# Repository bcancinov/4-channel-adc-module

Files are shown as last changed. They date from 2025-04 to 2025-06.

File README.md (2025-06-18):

# 4 Channel ADC Module

**Version 0.1** – Prototype for revision and discussion

This repository contains the schematic and supporting documentation for the **4 Channel ADC Module** prototype built in KiCad EDA v9.0.0.

## Table of Contents

1. [Overview](#overview)
2. [Features](#features)
3. [Repository Contents](#repository-contents)
4. [Schematic](#schematic)
5. [User Manual](#user-manual)
6. [Usage](#usage)
7. [Bill of Materials](#bill-of-materials)
8. [License](#license)
9. [Author](#author)

## Overview

The 4 Channel ADC Module is a daughterboard for Trenz TE0720 modules (Zynq™ 7020) designed by NOIRLab to provide high-precision analog-to-digital conversion. It features a multi‑rail power system, low‑noise analog front‑end, high‑speed SAR ADCs, clock synchronization, and both USB-C and Ethernet interfaces.

The following two views show the top and bottom of the assembled PCB, annotated with component group numbers. Refer to the list below for component descriptions.

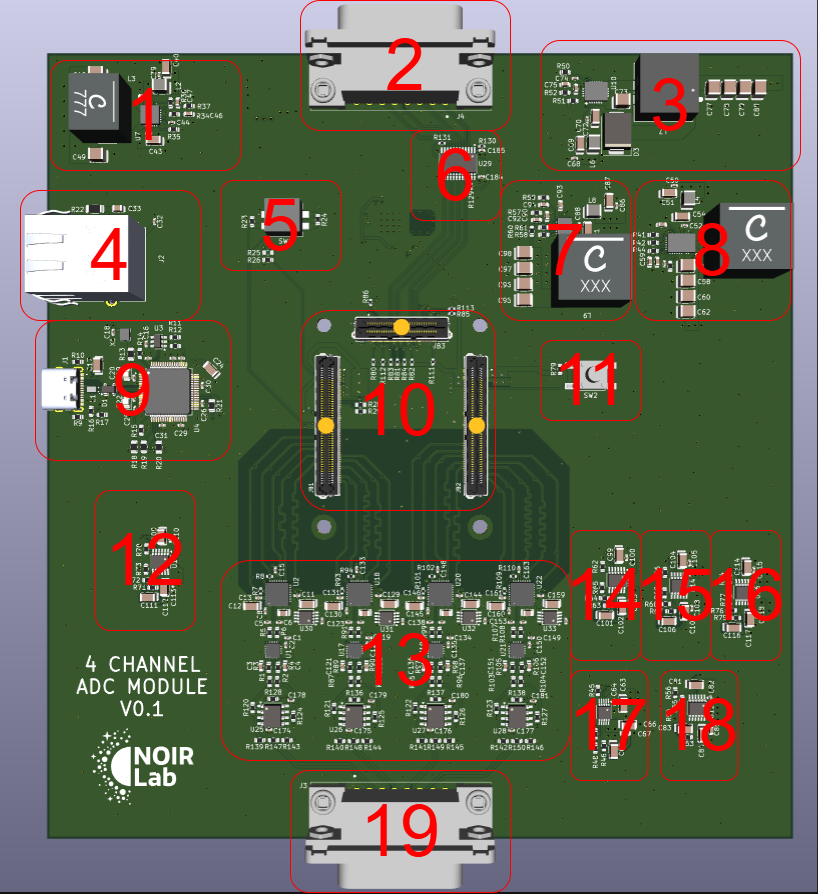
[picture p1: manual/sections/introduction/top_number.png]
Top Side PCB Diagram


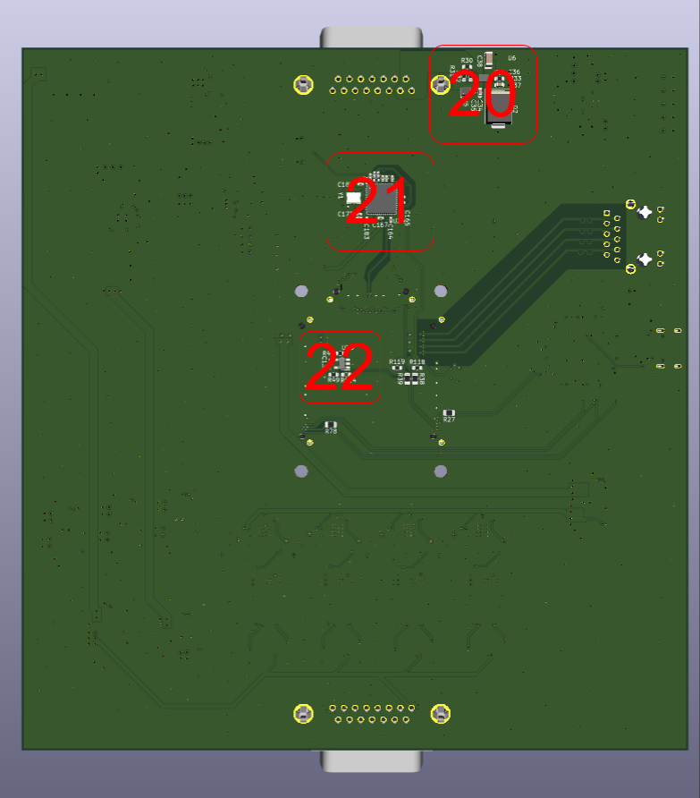
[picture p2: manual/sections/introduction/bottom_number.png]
Bottom Side PCB Diagram


1. Digital 3.3 V DC‑DC Converter.
2. Backplane Connector.
3. Analog –15.5 V DC‑DC Converter.
4. RJ45 Ethernet Connector.
5. Zynq‑SoC Module Mode Switch.
6. Voltage Translator IC.
7. Analog 5.5 V DC‑DC Converter.
8. Analog 15.5 V DC‑DC Converter.
9. FTDI USB‑C Interface.
10. Zynq‑SoC Module.
11. Zynq‑SoC Reset Button.
12. Digital 2.5 V LDO.
13. 4 Channel Video Front‑End and ADC.
14. Analog 5 V LDO.
15. Analog 2.5 V LDO.
16. Analog 4.2 V LDO.
17. Analog 15 V LDO.
18. Analog –15 V LDO.
19. Video Input Connector.
20. 12 V Power Input Protection.
21. Clock Generator.
22. EEPROM.

## Features

* **Dimensions:** 162 mm × 171 mm, six‑layer impedance‑controlled PCB
* **ADC Front‑End:** Fully differential, low‑noise amplifiers (ADA4945‑1 & LTC2387‑18)
* **Main Processor:** Zynq 7020 SoC-Module (TE0720-04-62I33MA)
* **Clock Gen:** Si5342‑D jitter attenuator for 10 MHz sync
* **Interfaces:** USB‑C (FT2232HL), Gigabit Ethernet (RJ45)
* **Power:** 12 V VIN protection, multi‑rail DC‑DC converters & LDOs
* **Backplane:** Sync clock, start, error, power rails

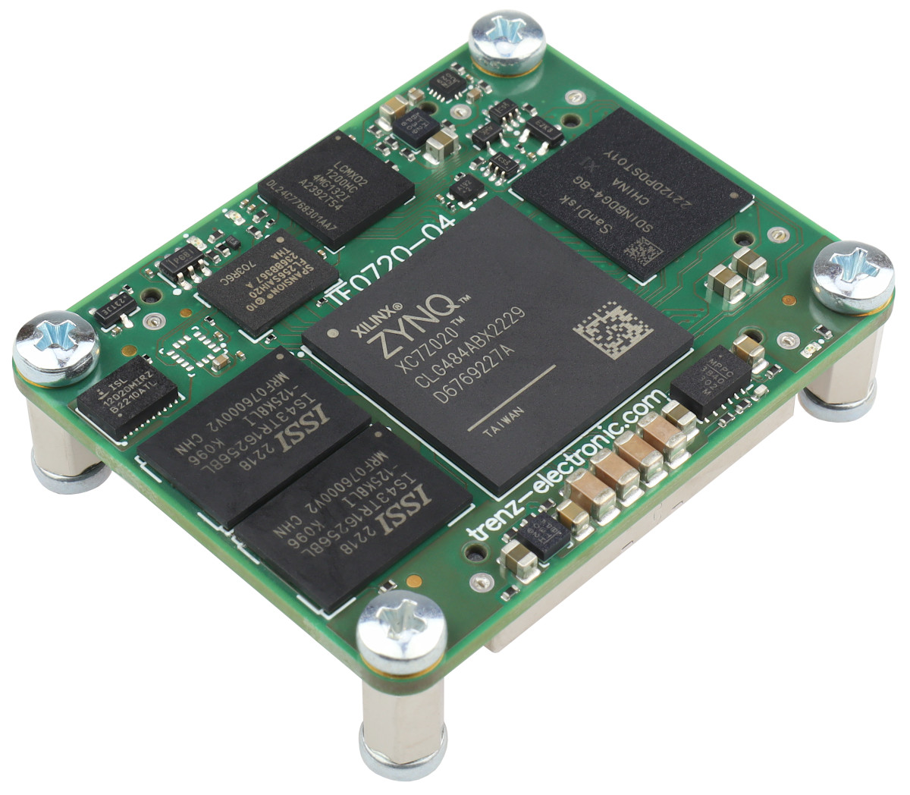
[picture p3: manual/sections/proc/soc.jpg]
Zynq 7020 SoC-Module


* `README.md` – This file
* `BOM.csv` – Bill of Materials
* `adc_board_prot.pdf` – Complete schematic PDF
* `adc_board_prot.kicad_pro` – KiCad project file
* `*.kicad_sch` – Schematic sheets (power, clock\_gen, adc, ftdi, ethernet, connectors, converters, misc, b2b\_jb1-3, power variants)
* `*.kicad_pcb` – PCB layout file
* `*.kicad_prl`, `*.kicad_prl` – PCB drill/paper list
* `*.kicad_sym`, `lib.kicad_sym` – Symbol libraries
* `lib.pretty/` – Footprint library

Other directories:

* `sim/` – LTSpice & LTPowerCAD simulations
* `step/` – STEP model files
* `docs/` – Documentation sources
* `manual/` – User manual PDF

## Schematic

The complete schematic is available as a PDF:

* [Download the schematic (PDF)](./adc_board_prot.pdf)

## User Manual

A detailed manual covering module description, power rails, front‑end design, and connectors can be found here:

* [Read the user manual (PDF)](manual/manual.pdf)

## Usage

1. Install [KiCad EDA 9.0.0](https://www.kicad.org).
2. Open **adc\_board\_prot.kicad\_pro** in KiCad.
3. Review schematic and BOM before fabrication.
4. Use the manual for detailed functional descriptions and assembly notes.

## Bill of Materials

A complete list of components and part numbers is provided in:

* `BOM.csv`

## License

This project is released under the **MIT License**.

## Author

**Braulio Cancino Vera**
NOIRLab
[braulio.cancino@noirlab.edu](mailto:braulio.cancino@noirlab.edu)
Date: June 17, 2025

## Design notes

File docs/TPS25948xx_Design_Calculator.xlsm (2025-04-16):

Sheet: Calculation Sheet
TPS25948xx Design Calculation Tool
 | Constants Cells
 | Input/SelectCells
 | Calculation Cells
 | Calculated, but can be over-ridden by user
 | Error Cells, Must be Fixed
Parameter | Description | Value | Units | Tolerance | Recommended Value
VIN (max) | Maximum Operating input voltage (magnitude) | 12.00 | V
OVLO Set Point | Desired Over Voltage Lockout Set Point | 14.00 | V | 3.0%
UVLO Set Point | Desired Undervoltage Threshold (VIN Rising) | 10.00 | V | 3.0%
VUVP | Internal Undervoltage Protection Threshold (VIN Rising) | 2.53 | V | 3.0%
Cout | Load Capacitance | 50.0 | uF | 10.0%
 | Is there downstream load present other than load cap at startup? | YES
VONTH (CR) (V) | constant resistance load turn on threshold voltage | 0.0 | V
RLOAD (STARTUP) (Ω) | CR load at startup | 4.0 | Ohm
VONTH (CC) (V) | constant current load turn on threshold voltage | 3.0 | V
ILOAD (STARTUP) (A) | CC load at startup | 0.0 | A
VONTH (CP) (V) | constant power load turn on threshold voltage | 8.0 | V
PLOAD (STARTUP) (W) | CP load at startup | 0.0 | W
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

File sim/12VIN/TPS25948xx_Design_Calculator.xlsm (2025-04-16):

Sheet: Calculation Sheet
TPS25948xx Design Calculation Tool
 | Constants Cells
 | Input/SelectCells
 | Calculation Cells
 | Calculated, but can be over-ridden by user
 | Error Cells, Must be Fixed
Parameter | Description | Value | Units | Tolerance | Recommended Value
VIN (max) | Maximum Operating input voltage (magnitude) | 13.00 | V
OVLO Set Point | Desired Over Voltage Lockout Set Point | 14.00 | V | 3.0%
UVLO Set Point | Desired Undervoltage Threshold (VIN Rising) | 10.00 | V | 3.0%
VUVP | Internal Undervoltage Protection Threshold (VIN Rising) | 2.53 | V | 3.0%
Cout | Load Capacitance | 10.0 | uF | 10.0%
 | Is there downstream load present other than load cap at startup? | YES
VONTH (CR) (V) | constant resistance load turn on threshold voltage | 0.0 | V
RLOAD (STARTUP) (Ω) | CR load at startup | 4.0 | Ohm
VONTH (CC) (V) | constant current load turn on threshold voltage | 3.0 | V
ILOAD (STARTUP) (A) | CC load at startup | 0.0 | A
VONTH (CP) (V) | constant power load turn on threshold voltage | 8.0 | V
PLOAD (STARTUP) (W) | CP load at startup | 0.0 | W
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

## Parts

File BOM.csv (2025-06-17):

Reference | Value | Qty | M | MPN | Description
C1,C2,C8,C9,C11,C13,C15,C16,C18,C20,C21,C23,C25,C26,C27,C28,C29,C30,C31,C32,C35,C39,C41,C50,C52,C56,C64,C68,C70,C74,C82,C86,C88,C100,C103,C105,C108,C110,C113,C115,C118,C119,C120,C126,C127,C129,C131,C132,C133,C134,C135,C141,C142,C144,C146,C148,C149,C150,C156,C157,C159,C161,C163,C174,C175,C176,C177,C178,C179,C180,C181,C184,C185 | 0.1uF | 73 | MURATA | GCM155R71H104KE02J | 0.1 µF ±10% 50V Ceramic Capacitor X7R 0402 (1005 Metric)
C3,C4,C121,C122,C136,C137,C151,C152 | 300pF | 8 | MURATA | GCM1885C2A301FA16J | 300 pF ±1% 100V Ceramic Capacitor C0G, NP0 0603 (1608 Metric)
C5,C6,C123,C124,C138,C139,C153,C154 | 180pF | 8 | MURATA | GRT1555C1H181FA02D | 180 pF ±1% 50V Ceramic Capacitor C0G, NP0 0402 (1005 Metric)
C7,C125,C140,C155 | 10uF | 4 | MURATA | GRM21BZ71C106KE15L | 10 µF ±10% 16V Ceramic Capacitor X7R 0805 (2012 Metric)
C10,C12,C17,C24,C38,C40,C43,C51,C54,C69,C72,C87,C91,C128,C130,C143,C145,C158,C160 | 10uF | 19 | TAIYO | GMK316AB7106KL-TR | 10 µF ±10% 35V Ceramic Capacitor X7R 1206 (3216 Metric)
C14,C42,C71,C89,C182,C183 | 0.1uF | 6 | MURATA | GCM155R71C104KA55J | 0.1 µF ±10% 16V Ceramic Capacitor X7R 0402 (1005 Metric)
C19,C22 | 1uF | 2 | MURATA | GCM21BR71H105KA03L | 1 µF ±10% 50V Ceramic Capacitor X7R 0805 (2012 Metric)
C33 | 100pF | 1 | WURTH | 885342207015 | 100 pF ±10% 1000V (1kV) Ceramic Capacitor X7R 0805 (2012 Metric)
C34 | 1uF | 1 | TDK | CGA3E1X7R1V105K080DC | 1 µF ±10% 35V Ceramic Capacitor X7R 0603 (1608 Metric)
C36 | 2.7nF | 1 | MURATA | GRM1885C1H272JA01D | 2700 pF ±5% 50V Ceramic Capacitor C0G, NP0 0603 (1608 Metric)
C37 | 4.3nF | 1 | MURATA | GRM1885C1H432JA01D | 4300 pF ±5% 50V Ceramic Capacitor C0G, NP0 0603 (1608 Metric)
C44 | 10nF | 1 | MURATA | GCM155R71H103KA55D | 10000 pF ±10% 50V Ceramic Capacitor X7R 0402 (1005 Metric)
C45 | 1uF | 1 | TAIYO | UMK107AB7105KA-T | 1 µF ±10% 50V Ceramic Capacitor X7R 0603 (1608 Metric)
C46 | 220p | 1 | MURATA | GCM1885C2A221FA16D | 220 pF ±1% 100V Ceramic Capacitor C0G, NP0 0603 (1608 Metric)
C47 | 47pF | 1 | MURATA | GCM1885C2A470FA16D | 47 pF ±1% 100V Ceramic Capacitor C0G, NP0 0603 (1608 Metric)
C48,C49,C57,C58,C60,C62,C77,C78,C79,C80,C95,C96,C97,C98 | 47u | 14 | TAIYO YUDEN | TMK325ABJ476MM-P | 47 µF ±20% 25V Ceramic Capacitor X5R 1210 (3225 Metric)
C55 | 4.7u | 1 | MURATA | GRT188R61E475KE13D | 4.7 µF ±10% 25V Ceramic Capacitor X5R 0603 (1608 Metric)
C59,C75 | 1nF | 2 | MURATA | GCM1885C2A102JA16D | 1000 pF ±5% 100V Ceramic Capacitor C0G, NP0 0603 (1608 Metric)
C61 | 5.1pF | 1 | KEMET | CBR06C519C5GACAUTO | 5.1 pF ±0.25pF 50V Ceramic Capacitor C0G, NP0 0603 (1608 Metric)
C63,C65,C66,C81,C83,C84,C99,C101,C102,C104,C106,C107,C109,C111,C112,C114,C116,C117 | 4.7uF | 18 | MURATA | GRM31CZ72A475KE11L | 4.7 µF ±10% 100V Ceramic Capacitor X7R 1206 (3216 Metric)
C67,C85 | 0.1uF | 2 | TAIYO | HMK107B7104KAHT | 0.1 µF ±10% 100V Ceramic Capacitor X7R 0603 (1608 Metric)
C73 | 4.7uF | 1 | KYOCERA | 12101C475K4Z2A | 4.7 µF ±10% 100V Ceramic Capacitor X7R 1210 (3225 Metric)
C76 | 27pF | 1 | MURATA | GCM1885C2A270JA16D | 27 pF ±5% 100V Ceramic Capacitor C0G, NP0 0603 (1608 Metric)
C90 | 150pF | 1 | KYOCERA | KGM15ACG1E151FT | 150 pF ±1% 25V Ceramic Capacitor C0G, NP0 0603 (1608 Metric)
C92 | 3nF | 1 | MURATA | GCM1885C1H302GA16D | 3000 pF ±2% 50V Ceramic Capacitor C0G, NP0 0603 (1608 Metric)
C93,C94 | 1uF | 2 | TAIYO | GMK107AB7105KAHT | 1 µF ±10% 35V Ceramic Capacitor X7R 0603 (1608 Metric)
C162,C164,C165,C166,C167,C168,C169,C170,C171,C172,C173 | 1uF | 11 | VENKEL | C0402X7R100-105KNP-CT | 1 µF ±10% 10V Ceramic Capacitor X7R 0402 (1005 Metric)
D1 | PRTR5V0U2X,215 | 1 | NEXPERIA | PRTR5V0U2X,215 | Ultra low capacitance double rail-to-rail ESD protection diode, SOT-143
D2 | B520C-13-F | 1 | DIODES | B520C-13-F | DIODE SCHOTTKY 20V 5A SMC
D3 | B560CX | 1 | DIODES | B560CX-13 | Diode 60 V 5A Surface Mount SMC
J1 | USB4105-GF-A | 1 | GCT | USB4105-GF-A | USB-C (USB TYPE-C) USB 2.0 Receptacle Connector 24 (16+8 Dummy) Position Surface Mount, Right Angle; Through Hole
J2 | TMJG4820GENL | 1 | TAOGLAS | TMJG4820GENL | 1 Port RJ45Through Hole 1G Base-T, AutoMDIX
J3,J4 | 5747841-4 | 2 | TE | 5747841-4 | 15-pin D-SUB connector, pins (male) (low-density/2 columns), Mounting Hole
JB1,JB2 | TE0720-JB1,TE0720-JB2 | 2 | SAMTEC | LSHM-150-04.0-L-DV-A-S-K-TR | 100 Position Connector Self Mating, Non-Gendered, Hermaphroditic Surface Mount Gold
JB3 | TE0720-JB3 | 1 | SAMTEC | LSHM-130-04.0-L-DV-A-S-K-TR | 60 Position Connector Self Mating, Non-Gendered, Hermaphroditic Surface Mount Gold
L1 | 744233670 | 1 | WURTH | 744233670 | 2 Line Common Mode Choke Surface Mount 67 Ohms 320mA DCR 240mOhm
L2,L4,L6,L8 | 250 nH | 4 | WURTH ELEKTRONIK | 74479290125 | 250 nH Unshielded Molded Inductor 9.35 A 31mOhm Max 1210 (3225 Metric)
L3 | 0.8uH | 1 | COILCRAFT | XGL1010-801MED | 800 nH Shielded Molded Inductor 48 A 1.1mOhm Max Nonstandard
L5,L9 | 2.2uH | 2 | COILCRAFT | XGL1313-222MED | 2.2 µH Shielded Molded Inductor 45.1 A 1.6mOhm Max 2-SMD,Inductor
L7 | 3.3u | 1 | EATON | DRQ125-3R3-R | Shielded 2 Coil Inductor Array 12.34 µH Inductance - Connected in Series 3.084 µH Inductance - Connected in Parallel 6.3mOhm DC Resistance (DCR) - Parallel 9.26 A Nonstandard
R1,R2,R3,R4,R87,R88,R89,R90,R95,R96,R97,R98,R103,R104,R105,R106,R120,R121,R122,R123,R124,R125,R126,R127 | 1k | 24 | PANASONIC | ERA-3AEB102V | 1 kOhms ±0.1% 0.1W, 1/10W Chip Resistor 0603 (1608 Metric) Automotive AEC-Q200 Thin Film
R5,R6,R91,R92,R99,R100,R107,R108 | 24.9 | 8 | VISHAY | CRCW060324R9FKEA | 24.9 Ohms ±1% 0.1W, 1/10W Chip Resistor 0603 (1608 Metric) Automotive AEC-Q200 Thick Film
R7,R8,R93,R94,R101,R102,R109,R110,R117 | 100 | 9 | VISHAY | CRCW0402100RFKEDHP | 100 Ohms ±1% 0.2W, 1/5W Chip Resistor 0402 (1005 Metric) Automotive AEC-Q200, Pulse Withstanding Thick Film
R9,R10 | 5.1k | 2 | VISHAY | CRCW06035K10FKEA | 5.1 kOhms ±1% 0.1W, 1/10W Chip Resistor 0603 (1608 Metric) Automotive AEC-Q200 Thick Film
R11 | 2k | 1 | VISHAY | CRCW06032K00FKEA | 2 kOhms ±1% 0.1W, 1/10W Chip Resistor 0603 (1608 Metric) Automotive AEC-Q200 Thick Film
R12,R17,R23,R24,R25,R28,R29,R40,R60,R79,R118,R119,R129,R130,R131,R139,R140,R141,R142,R143,R144,R145,R146 | 10K,10k | 23 | VISHAY | CRCW060310K0FKEA | 10 kOhms ±1% 0.1W, 1/10W Chip Resistor 0603 (1608 Metric) Automotive AEC-Q200 Thick Film
R13,R18,R19,R20,R21,R27,R38,R39,R78 | 22 | 9 | VISHAY | CRCW080522R0FKEAHP | 22 Ohms ±1% 0.5W, 1/2W Chip Resistor 0805 (2012 Metric) Automotive AEC-Q200, Pulse Withstanding Thick Film
R14 | 12k | 1 | VISHAY | CRCW060312K0FKEA | 12 kOhms ±1% 0.1W, 1/10W Chip Resistor 0603 (1608 Metric) Automotive AEC-Q200 Thick Film
R15,R48,R56,R61,R65,R69,R73,R77,R147,R148,R149,R150 | 1k | 12 | VISHAY | CRCW06031K00FKEA | 1 kOhms ±1% 0.1W, 1/10W Chip Resistor 0603 (1608 Metric) Automotive AEC-Q200 Thick Film
R16 | 4k7 | 1 | VISHAY | CRCW06034K70FKEA | 4.7 kOhms ±1% 0.1W, 1/10W Chip Resistor 0603 (1608 Metric) Automotive AEC-Q200 Thick Film
R22 | 1M | 1 | VISHAY | CRCW12061M00JNEAHP | 1 MOhms ±5% 0.75W, 3/4W Chip Resistor 1206 (3216 Metric) Automotive AEC-Q200, Pulse Withstanding Thick Film
R26,R45,R49,R54,R62,R66,R70,R74,R114 | 0 | 9 | VISHAY | CRCW06030000Z0EA | 0 Ohms Jumper Chip Resistor 0603 (1608 Metric) Automotive AEC-Q200 Thick Film
R30 | 470k | 1 | VISHAY | CRCW0603470KFKEA | 470 kOhms ±1% 0.1W, 1/10W Chip Resistor 0603 (1608 Metric) Automotive AEC-Q200 Thick Film
R31,R44 | 18.7k | 2 | VISHAY | CRCW060318K7FKEA | 18.7 kOhms ±1% 0.1W, 1/10W Chip Resistor 0603 (1608 Metric) Automotive AEC-Q200 Thick Film
R32 | 46.4k | 1 | VISHAY | CRCW060346K4FKEA | 46.4 kOhms ±1% 0.1W, 1/10W Chip Resistor 0603 (1608 Metric) Automotive AEC-Q200 Thick Film
R33 | 1050 | 1 | VISHAY | CRCW06031K05FKEA | 1.05 kOhms ±1% 0.1W, 1/10W Chip Resistor 0603 (1608 Metric) Automotive AEC-Q200 Thick Film
R34 | 6.98k | 1 | VISHAY | CRCW06036K98FKTA | 6.98 kOhms ±1% 0.1W, 1/10W Chip Resistor 0603 (1608 Metric) Automotive AEC-Q200 Thick Film
R35 | 17.8k | 1 | VISHAY | CRCW060317K8FKEA | 17.8 kOhms ±1% 0.1W, 1/10W Chip Resistor 0603 (1608 Metric) Automotive AEC-Q200 Thick Film
R36 | 100k | 1 | VISHAY | CRCW0603100KFKEA | 100 kOhms ±1% 0.1W, 1/10W Chip Resistor 0603 (1608 Metric) Automotive AEC-Q200 Thick Film
R37 | 22.1k | 1 | VISHAY | CRCW060322K1FKEA | 22.1 kOhms ±1% 0.1W, 1/10W Chip Resistor 0603 (1608 Metric) Automotive AEC-Q200 Thick Film
R41 | 110k | 1 | VISHAY | CRCW0603110KFKEA | 110 kOhms ±1% 0.1W, 1/10W Chip Resistor 0603 (1608 Metric) Automotive AEC-Q200 Thick Film
R42 | 7.5k | 1 | VISHAY | CRCW06037K50FKEA | 7.5 kOhms ±1% 0.1W, 1/10W Chip Resistor 0603 (1608 Metric) Automotive AEC-Q200 Thick Film
R43,R52 | 20k | 2 | VISHAY | CRCW060320K0FKEA | 20 kOhms ±1% 0.1W, 1/10W Chip Resistor 0603 (1608 Metric) Automotive AEC-Q200 Thick Film
R46,R53 | 150k | 2 | VISHAY | TNPW0603150KBEEA | 150 kOhms ±0.1% 0.21W Chip Resistor 0603 (1608 Metric) Anti-Sulfur, Automotive AEC-Q200, Moisture Resistant Thin Film
R47,R55 | 47.5k | 2 | VISHAY | CRCW060347K5FKEA | 47.5 kOhms ±1% 0.1W, 1/10W Chip Resistor 0603 (1608 Metric) Automotive AEC-Q200 Thick Film
R50 | 43.2k | 1 | VISHAY | CRCW060343K2FKEA | 43.2 kOhms ±1% 0.1W, 1/10W Chip Resistor 0603 (1608 Metric) Automotive AEC-Q200 Thick Film
R51 | 187k | 1 | VISHAY | CRCW0603187KFKEA | 187 kOhms ±1% 0.1W, 1/10W Chip Resistor 0603 (1608 Metric) Automotive AEC-Q200 Thick Film
R57 | 3.09k | 1 | VISHAY | CRCW06033K09FKEA | 3.09 kOhms ±1% 0.1W, 1/10W Chip Resistor 0603 (1608 Metric) Automotive AEC-Q200 Thick Film
R58 | 47k | 1 | VISHAY | CRCW060347K0FKEA | 47 kOhms ±1% 0.1W, 1/10W Chip Resistor 0603 (1608 Metric) Automotive AEC-Q200 Thick Film
R59 | 54.9k | 1 | VISHAY | CRCW060354K9FKEA | 54.9 kOhms ±1% 0.1W, 1/10W Chip Resistor 0603 (1608 Metric) Automotive AEC-Q200 Thick Film
R63 | 49.9k | 1 | VISHAY | TNPW060349K9BEEA | 49.9 kOhms ±0.1% 0.21W Chip Resistor 0603 (1608 Metric) Anti-Sulfur, Automotive AEC-Q200, Moisture Resistant Thin Film
R64 | 14k | 1 | VISHAY | CRCW060314K0FKEA | 14 kOhms ±1% 0.1W, 1/10W Chip Resistor 0603 (1608 Metric) Automotive AEC-Q200 Thick Film
R67,R71 | 24.9k | 2 | VISHAY | TNPW060324K9BEEN | 24.9 kOhms ±0.1% 0.21W Chip Resistor 0603 (1608 Metric) Anti-Sulfur, Automotive AEC-Q200, Moisture Resistant Thin Film
R68,R72 | 6.98k | 2 | VISHAY | CRCW06036K98FKEA | 6.98 kOhms ±1% 0.1W, 1/10W Chip Resistor 0603 (1608 Metric) Automotive AEC-Q200 Thick Film
R75 | 42.2k | 1 | VISHAY | TNPW060342K2BEEA | 42.2 kOhms ±0.1% 0.21W Chip Resistor 0603 (1608 Metric) Anti-Sulfur, Automotive AEC-Q200, Moisture Resistant Thin Film
R76 | 13k | 1 | VISHAY | CRCW060313K0FKEA | 13 kOhms ±1% 0.1W, 1/10W Chip Resistor 0603 (1608 Metric) Automotive AEC-Q200 Thick Film
R80,R81,R82,R83,R84,R85,R86,R111,R112,R113 | 100k | 10 | VISHAY | CRCW0402100KFKED | 100 kOhms ±1% 0.063W, 1/16W Chip Resistor 0402 (1005 Metric) Automotive AEC-Q200 Thick Film
R128,R136,R137,R138 | 665 | 4 | VISHAY | CRCW0603665RFKEA | 665 Ohms ±1% 0.1W, 1/10W Chip Resistor 0603 (1608 Metric) Automotive AEC-Q200 Thick Film
SW1 | SDA02H1SBDR | 1 | C&K | SDA02H1SBDR | Dip Switch SPST 2 Position Surface Mount Slide (Standard) Actuator 25mA 24VDC
SW2 | FSM6JSMATR | 1 | TE | FSM6JSMATR | Tactile Switch SPST-NO Top Actuated Surface Mount
U1,U17,U19,U21 | ADA4945-1 | 4 | ANALOG | ADA4945-1ACPZ-RL | ADC Driver IC Data Acquisition 16-LFCSP (3x3)
U2,U18,U20,U22 | LTC2387-18 | 4 | ANALOG | LTC2387IUH-18#TRPBF | 18 Bit Analog to Digital Converter 1 Input 1 SAR 32-QFN (5x5)
U3 | 93AA56BT-I/OT | 1 | MICROCHIP | 93AA56BT-I/OT | Serial EEPROM, 93 Series, 16-bit word, 1.8V, SOT-23
U4 | FT2232HL | 1 | FTDI | FT2232HL-REEL | USB Bridge, USB to UART,FIFO USB 2.0 UART Interface 64-LQFP (10x10)
U5 | TVS1800DRV | 1 | TEXAS INSTRUMENTS | TVS1800DRVR | Flat-Clamp Surge Protection Device. 18Vrwm, WSON-6
U6 | TPS259480AYWPR | 1 | TEXAS INSTRUMENTS | TPS259480AYWPR | Electronic Fuse Regulator High-Side 8A 12-DSBGA (2.43x1.74)
U7 | LT8642S | 1 | ANALOG | LT8642SEV#PBF | Buck Switching Regulator IC Positive Adjustable 0.597V 1 Output 10A 24-TFQFN Exposed Pad
U8 | LT8350S | 1 | ANALOG | LT8350SAV#PBF | Buck-Boost Switching Regulator IC Positive Adjustable 1V 1 Output 6A 32-TFQFN Exposed Pad, 28 Leads
U9 | LT3042 | 1 | ANALOG DEVICES | LT3042EMSE#TRPBF | 200mA, Adjustable, Ultralow Noise, Ultrahigh PSRR RF Linear Regulator, MSOP-10
U10 | LT3579 | 1 | ANALOG | LT3579EUFD#PBF | Boost, Charge Pump, Cuk, Flyback, SEPIC Switching Regulator IC Positive or Negative Adjustable 1.215V 1 Output 6A (Switch) 20-WFQFN Exposed Pad
U11 | LT3093 | 1 | ANALOG | LT3093EMSE#PBF | -200mA, Adjustable, Ultralow Noise, Ultrahigh PSRR RF Negative Linear Regulator, MSOP-12
U12 | LT8624S | 1 | ANALOG | LT8624SAV#PBF | Buck Switching Regulator IC Positive Adjustable 0V 1 Output 4A 20-TFQFN Exposed Pad
U13,U14,U15,U16 | LT3045 | 4 | ANALOG | LT3045EMSE#TRPBF | 500mA, Adjustable, Ultralow Noise, Ultrahigh PSRR Linear Regulator, MSOP-12
U23 | 24LC16BT-I/OT | 1 | MICROCHIP | 24LC16BT-I/OT | EEPROM Memory IC 16Kbit I2C 400 kHz 900 ns SOT-23-5
U24 | Si5342A-D | 1 | SKYWORKS | SI5342A-D-GM | Jitter Attenuator/Clock Multiplier, 2 channel, Fractional, 0.001-1028 MHz, QFN-44
U25,U26,U27,U28 | ADA4898-2 | 4 | ANALOG | ADA4898-2YRDZ-R7 | Dual High Voltage, Low Noise, Low Distortion, Unity-Gain Stable, High Speed Op Amp, SOIC-8-1EP
U29 | SN74AXC8T245-Q1 | 1 | TEXAS | SN74AXC8T245QPWRQ1 | Translation Transceiver 1 Element 8 Bit per Element Tri-State, Non-Inverted Output 24-TSSOP
U30,U31,U32,U33 | LTC6655BHMS8-4.096#PBF | 4 | ANALOG | LTC6655BHMS8-4.096#PBF | Series Voltage Reference IC Fixed 4.096V V ±0.025% 5 mA 8-MSOP
X1 | ECS-2520MVLC-120-CN-TR | 1 | ECS | ECS-2520MVLC-120-CN-TR
Y1 | CX3225SB48000D0FLJCC | 1 | KYOCERA | CX3225SB48000D0FLJCC | 48 MHz ±10ppm Crystal 8pF 50 Ohms 4-SMD, No Lead

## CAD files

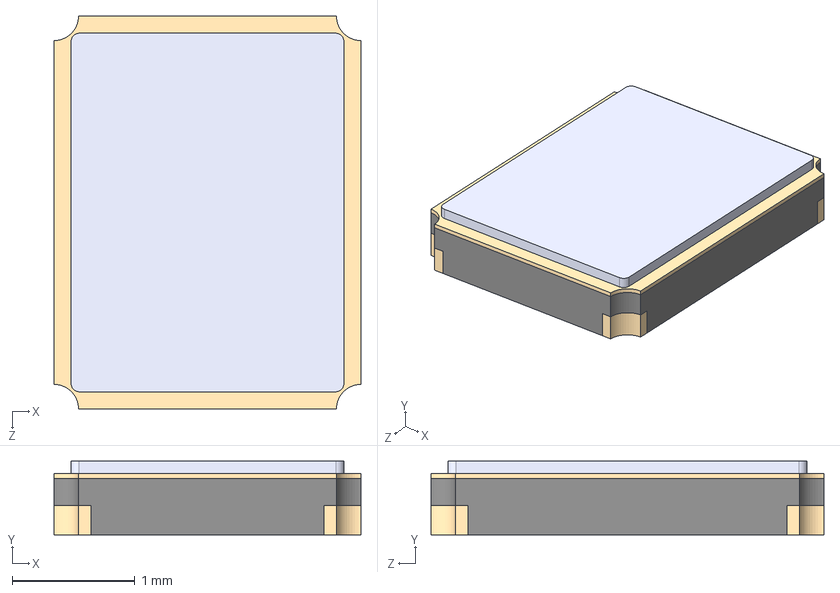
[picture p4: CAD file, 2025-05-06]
step/CX3225SB48000D0FLJCC.step
2.50 x 0.6 x 3.20 mm

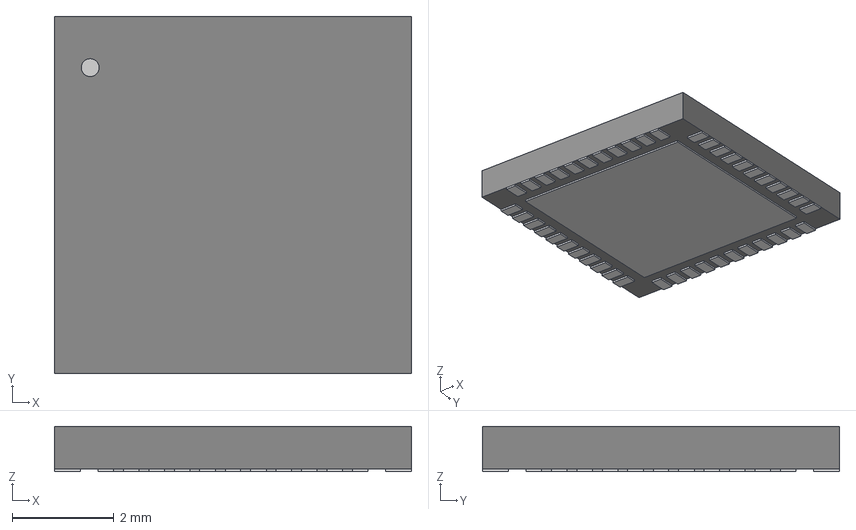
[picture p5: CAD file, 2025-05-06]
step/Si5342A-QFN44_SKY.step
7.01 x 7.01 x 0.892 mm

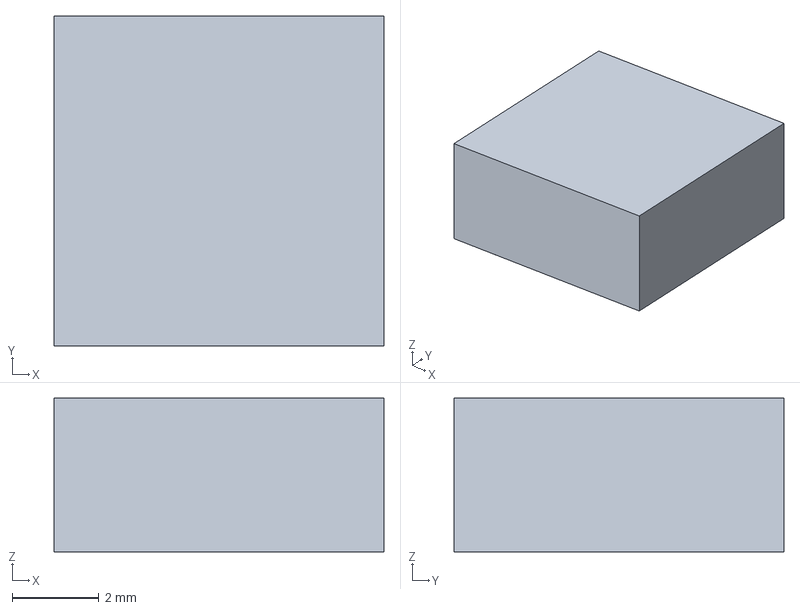
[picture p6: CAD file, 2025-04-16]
step/DRQ74.step
7.62 x 7.62 x 3.56 mm

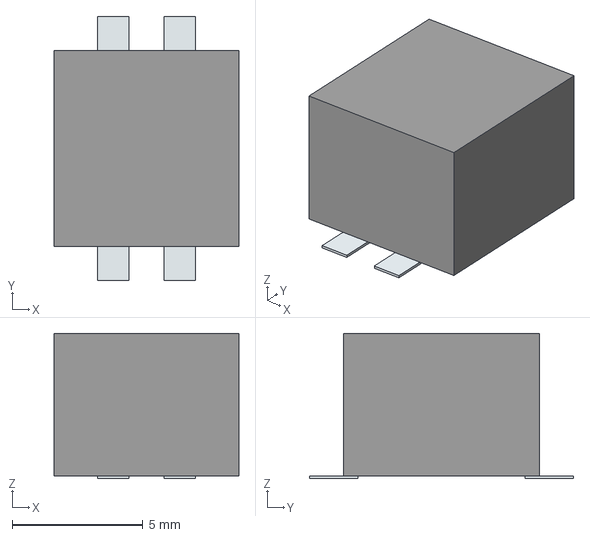
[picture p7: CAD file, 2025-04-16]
step/SDA02H1SBDR.stp
7.06 x 10.1 x 5.55 mm
Pins

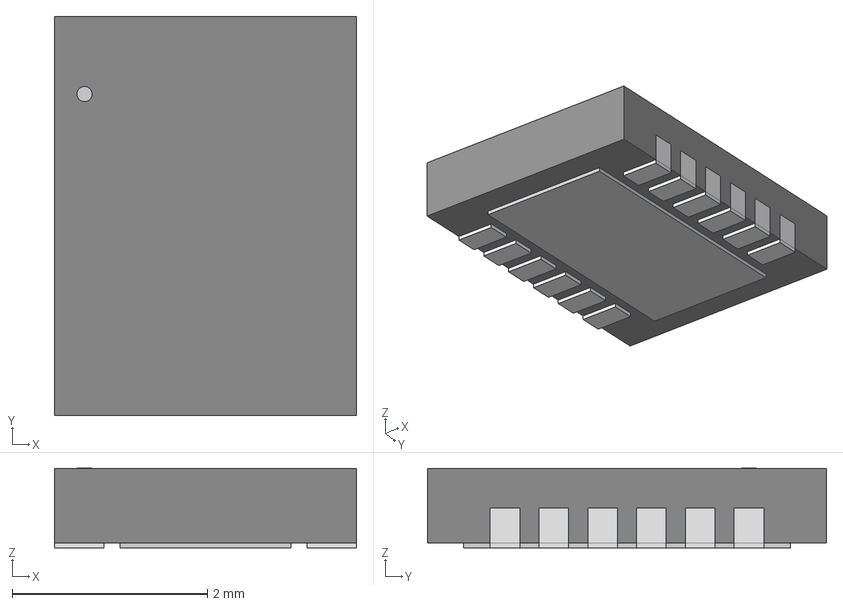
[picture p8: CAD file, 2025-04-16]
step/lt8334.step
3.10 x 4.09 x 0.815 mm

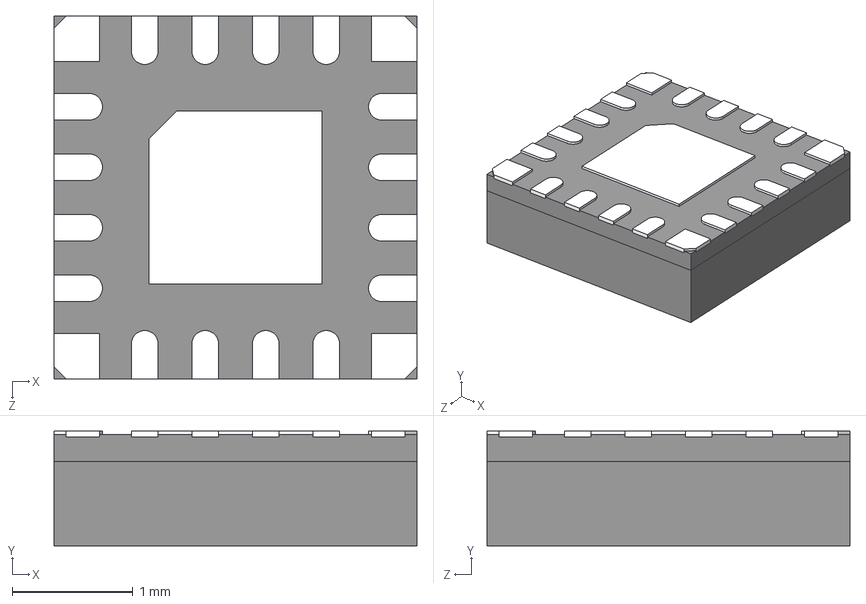
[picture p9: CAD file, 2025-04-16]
step/LT8337EV#PBF.stp
3.00 x 0.95 x 3.00 mm

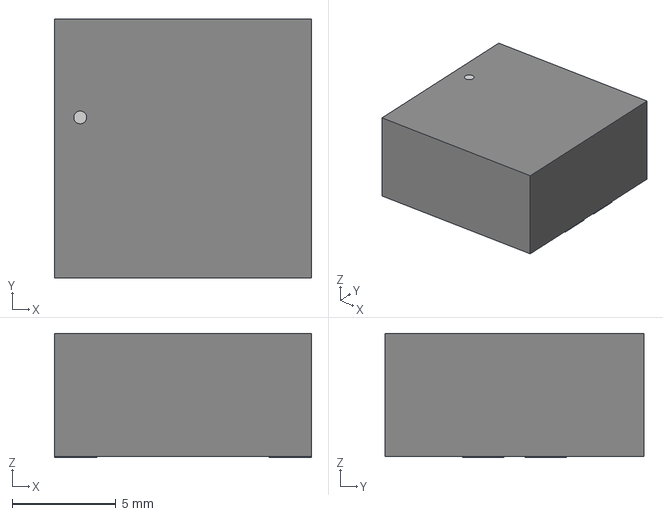
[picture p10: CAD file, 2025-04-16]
step/DRQ125.step
12.4 x 12.5 x 6.00 mm

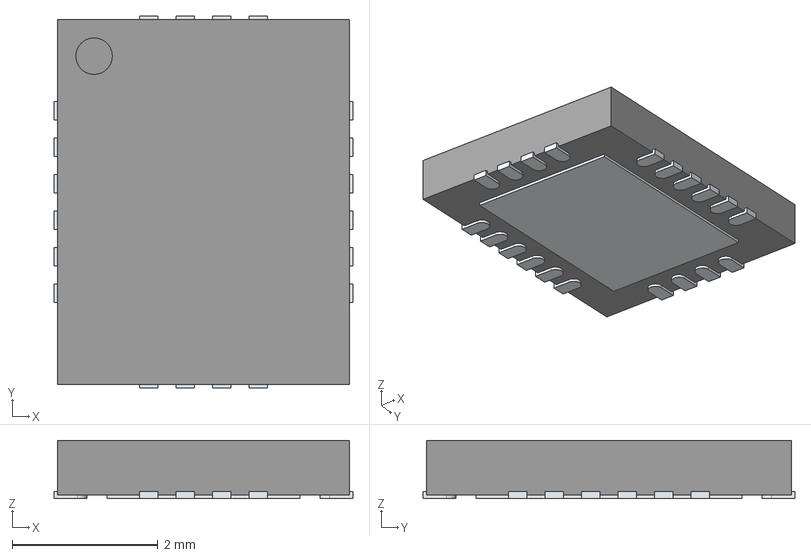
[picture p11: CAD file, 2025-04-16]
step/LT3579IUFD-1#PBF.stp
4.10 x 5.10 x 0.8 mm
ThermalPin
PinsArrayLR
PinsArrayTB

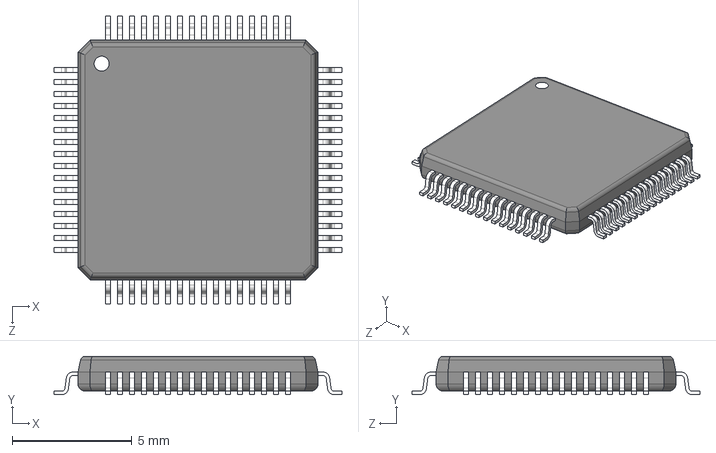
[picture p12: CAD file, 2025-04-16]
step/FT2232HL-REEL.step
12.0 x 1.60 x 12.0 mm

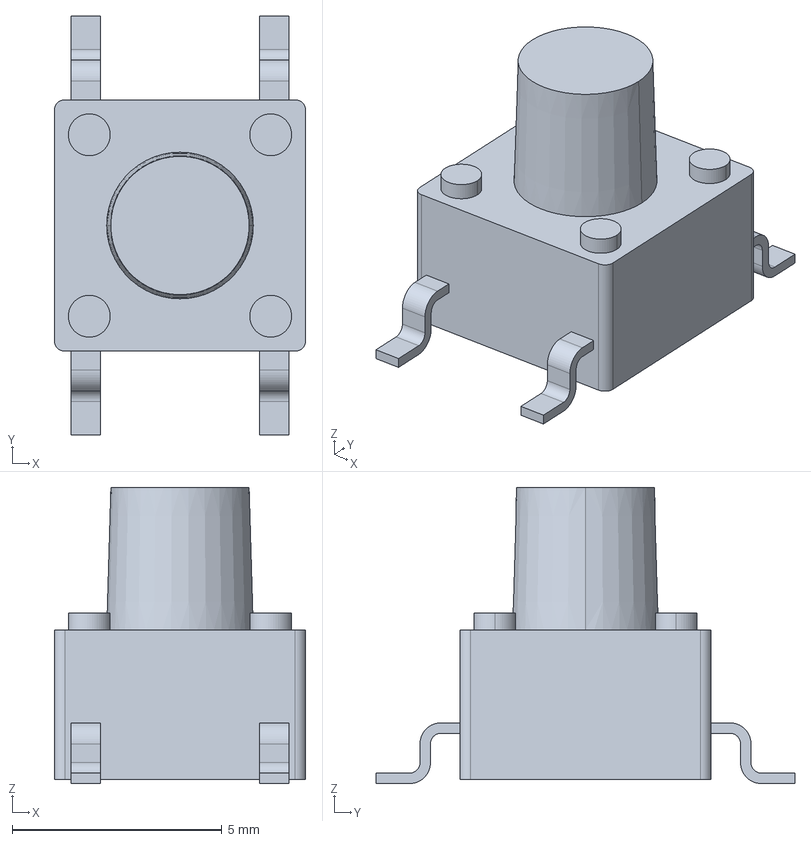
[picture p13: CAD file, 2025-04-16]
step/5-1437565-0.stp
6.00 x 10.0 x 7.07 mm

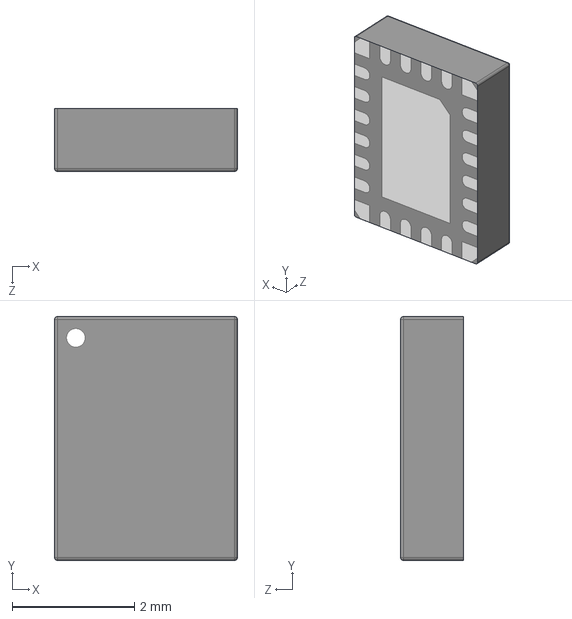
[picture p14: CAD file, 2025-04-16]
step/LT8624SAV#PBF.stp
3.00 x 4.00 x 1.03 mm

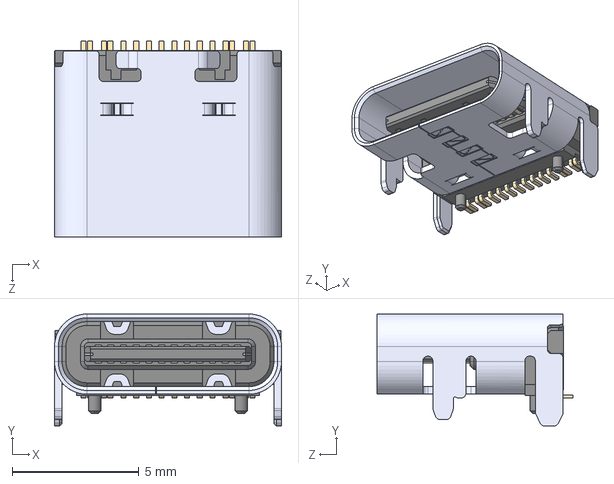
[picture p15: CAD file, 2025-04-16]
step/USB4105-GF-A.step
8.94 x 4.41 x 7.71 mm

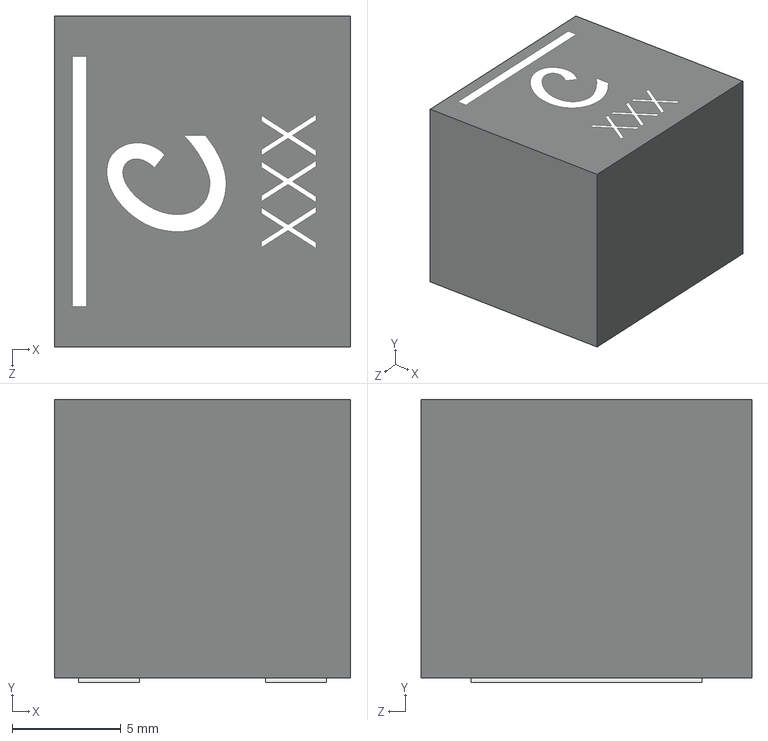
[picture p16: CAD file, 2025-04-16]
step/Coilcraft-XGL1313.step
13.6 x 13.0 x 15.2 mm

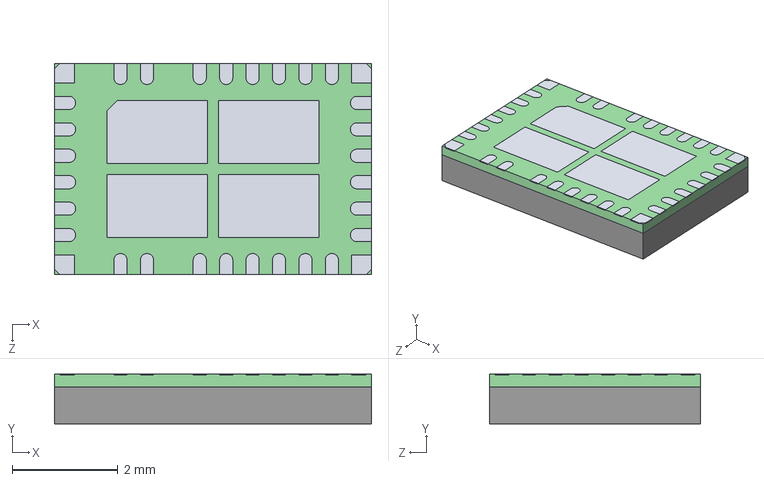
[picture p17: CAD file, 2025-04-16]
step/LT8350SAV#PBF.stp
6.00 x 0.94 x 4.00 mm

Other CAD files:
step/EEHZA1E680XP.stp
step/LFCSP16_ADA4945-1ACPZ-R2_ADI.step
step/24LC16BT-I_OT.stp
step/LTC2387-18.step
step/5747841-4.stp
step/5747843-4.stp
step/6-534998-0.stp
step/65100516121.stp
step/796636-2.stp
step/Coilcraft-XGL1010.step
step/ECS-2520MVLC-120-CN-TR.stp
step/LSHM-130-04.0-L-DV-A-S-K-TR.stp
step/LT8642SIV#PBF.stp
step/PJ-202AH.step
step/TMJG4820GENL.STEP
step/TPS259480AYWPR.stp
step/WE-CNSW-HF-0805_rev1.stp

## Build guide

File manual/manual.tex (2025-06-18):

\documentclass[11pt,letterpaper]{article}

%----------------------------
%  Package Imports
%----------------------------
\usepackage[utf8]{inputenc}
\usepackage[T1]{fontenc}
\usepackage[english]{babel}

\usepackage[letterpaper,margin=25mm]{geometry}

\usepackage{tgtermes}        % TeX Gyre Termes (Times‐like). Swap to 'tgpagella' for Palatino style, etc.

% 2) Improve micro‐typography (protrusion + font expansion)
\usepackage{microtype}

% 3) Better “code” / monospaced font for any snippets
\usepackage{inconsolata}     % a clean, professional monospace

% 5) Slightly more vertical space between paragraphs (optional)
\usepackage{parskip}         % removes paragraph indentation, adds small skip

% 6) If you want “fancy” headers/footers (document title on the left, page number on the right, etc.)
\usepackage{fancyhdr}
\pagestyle{fancy}
\fancyhf{}                                  % clear all header/footer fields
\fancyhead[L]{\small NOIRLab\\ 4‐Channel ADC Module Prototype}  % left header
\fancyhead[R]{\small Version 0.1}           % right header
\fancyfoot[C]{\small \thepage}              % centered footer

% 7) For clickable, colored links in PDF
\usepackage[hidelinks]{hyperref}

% Math and symbols
\usepackage{amsmath,amssymb,mathtools}

% \usepackage{tikz}
\usepackage{circuitikz}
\usetikzlibrary{positioning, fit, calc}

% Load siunitx for SI units:
\usepackage{siunitx}
\sisetup{detect-all}

% define a general sqrt-unit macro:
\newcommand{\sqrtunit}[1]{%
  \ensuremath{%
    \sqrt{\text{\si{#1}}}%
  }%
}

% better tables
\usepackage{booktabs}

\usepackage{multicol}

% Figures and captions
\usepackage{graphicx}
\usepackage{caption}
\usepackage{subcaption}

% Hyperlinks and cross-referencing
\usepackage[hidelinks]{hyperref}

% Page geometry
% \usepackage[a4paper,margin=2.5cm]{geometry}

% Bibliography (if you cite datasheets or papers)
\usepackage{cite}

%----------------------------
%  Document Begins
%----------------------------
\begin{document}

% Title page
\title{4-Channel ADC Module Prototype\\Module Description and Analysis}
\author{Braulio Cancino Vera \\ National Optical-Infrared Astronomy Research Laboratory (NOIRLab)}
\date{Version 0.1}
\maketitle

% Table of Contents (clickable)
\tableofcontents
\clearpage

% Include each section in order
\input{sections/introduction.tex}
\newpage\input{sections/power.tex}
\newpage\input{sections/clock_gen.tex}
\newpage\input{sections/front_end_adc.tex}
\newpage\input{sections/proc.tex}
\newpage\input{sections/connectors.tex}
\newpage\input{sections/misc.tex}

% Bibliography (if needed)
% \bibliographystyle{ieeetr}
% \bibliography{bib/references}

\end{document}

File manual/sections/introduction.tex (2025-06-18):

\section{Introduction}
\label{sec:intro}

This document describes the schematic and functional operation of a 4-channel ADC module prototype, designed in KiCad 9. The module is one building block in a scalable detector-controller system: each board contains its own processor and plugs into a minimal backplane that provides:
\begin{itemize}
  \item A single \SI{12}{\volt} power rail.
  \item A \SI{10}{\mega\hertz} synchronization clock for the DC-DC converters and the detector sequencer
  \item A start signal indicating the beginning of an acquisition cycle.
  \item An emergency-stop line to flag a fault condition.
\end{itemize}
Each board also has its own Gigabit Ethernet port—for configuration, telemetry, and streaming video data

\autoref{fig:pcb_top} and \autoref{fig:pcb_bottom} show the PCB implementation of the 4-channel ADC prototype board with

\begin{multicols}{2}
  \begin{enumerate}
    \item Digital \SI{3.3}{\volt} DC-DC Converter.
    \item Backplane Connector.
    \item Analog \SI{-15.5}{\volt} DC-DC Converter.
    \item RJ45 Ethernet Connector.
    \item Zynq-Soc Module Mode Switch.
    \item Voltage Translator IC.
    \item Analog \SI{5.5}{\volt} DC-DC Converter.
    \item Analog \SI{15.5}{\volt} DC-DC Converter.
    \item FTDI USB-C Interface.
    \item Zynq-Soc Module.
    \item Zynq-Soc Reset Button.
    \item Digital \SI{2.5}{\volt} LDO.
    \item 4 Channel Video Front-End and ADC.
    \item Analog \SI{5}{\volt} LDO.
    \item Analog \SI{2.5}{\volt} LDO.
    \item Analog \SI{4.2}{\volt} LDO.
    \item Analog \SI{15}{\volt} LDO.
    \item Analog \SI{-15}{\volt} LDO.
    \item Video Input Connector.
    \item \SI{12}{\volt} Power Input Protection.
    \item Clock Generator.
    \item EEPROM.
  \end{enumerate}
\end{multicols}

\begin{figure}[!ht]
  \centering
   
  \caption{Top View of the 16.2 cm x 17.1 cm, six-layer PCB with impedance control, 4-channel ADC prototype board.}
  \label{fig:pcb_top}
\end{figure}

\begin{figure}[!ht]
  \centering
   
  \caption{Bottom View of the 16.2 cm x 17.1 cm, six-layer PCB with impedance control, 4-channel ADC prototype board.}
  \label{fig:pcb_bottom}
\end{figure}

In \autoref{fig:pcb_top}, most of the digital circuitry is clustered on the left side (from top view). Along the top edge you'll find the backplane connector and the DC-DC converters; along the bottom edge are the low-noise LDOs, the four ADC channels with their analog front end, and the input connector.

Immediately beside the top backplane connector, a jitter-attenuator clock generator takes the 10 MHz sync clock from the backplane and delivers a low-jitter reference to the Zynq SoC for the detector sequencer and DC-DC synchronization. A small I²C EEPROM stores the board's type and revision information.

At the center of the board sits a Trenz TE0720-04-62I33MA Zynq SoC-Module, which integrates an AMD Zynq™ 7020-2I, 1 GB of DDR3L RAM, and 8 GB of eMMC flash.

On the left digital side, a Gigabit-Ethernet RJ45 port interfaces with the Zynq SoC for configuration, telemetry, and streaming video data from the ADCs. An FTDI USB-C interface provides direct programming of the Zynq (without a separate JTAG adapter) and supplies a UART console link

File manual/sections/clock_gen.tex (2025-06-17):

\section{Clock Generator}

The clock generator derives an ultra-low-jitter timing reference from the single-ended \SI{10}{\mega\hertz} backplane synchronization signal (\texttt{CLOCK\_SYNC}). We use the Skyworks Si5342A-D jitter-attenuating clock multiplier, which provides:

\begin{itemize}
    \item Ultralow \SI{90}{\femto\second} RMS output jitter.
    \item Support for external crystals between \SI{25}{\mega\hertz} and \SI{54}{\mega\hertz}.
    \item SPI/I²C control interface.
    \item Zero-delay mode for minimal, deterministic input-to-output latency.
    \item Both single-ended and differential I/O.
\end{itemize}

The Si5342A-D “cleans” the backplane clock to produce a low-jitter reference. The Zynq SoC then employs this cleaned clock for its sequencer timing and to drive the DC-DC converters, reducing their switching noise and improving overall power-rail integrity.

In our design (see \autoref{fig:clock_gen}), a Kyocera AVX \SI{48}{\mega\hertz} $\pm$ 10ppm crystal provides the Si5342A-D's reference frequency. The device is configured in zero-delay mode to guarantee a fixed, repeatable phase relationship between \texttt{CLOCK\_SYNC} and the output clock to Zynq SoC. Configuration and status monitoring are handled over I²C via the Zynq SoC's. Finally, the Si5342A-D's differential \SI{2.5}{\volt} LVDS output is routed directly into one of the Zynq SoC's MRCC (Multi-Region Clock-Capable) input.

\begin{figure}[ht]
  \centering
  
  \caption{Si5342A-D Clock Generator Jitter Attenuator Circuit}
  \label{fig:clock_gen}
\end{figure}

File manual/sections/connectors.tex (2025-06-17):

\section{Connectors}

\subsection{Backplane Connector}

Backplane connector serves as the primary interface for power, control, and monitoring systems. It brings in an external \SI{12}{\volt} power rail to feed board DC-DC converters and \SI{3.3}{\volt} digital I/O like synchronization and interlocks. 

Selected backplane connector is TE Connectivity 5747841-4 15-position D-Sub plug male pins connector. \autoref{tab:backplane} shows backplane connector pinout.

\begin{table}[ht]
  \centering
  \begin{tabular}{l c l c l}
    \toprule
    Pin name  & Pin no.     & Dir. & Level            & Description                                \\
    \midrule
    12VIN     & 7, 8, 15        & —    & \SI{12}{\volt}   & External power input                       \\[3pt]
    BPI0      & 1               & In   & \SI{3.3}{\volt}  & 10\,\si{\mega\hertz} external sync clock  \\
    BPI1      & 9               & In   & \SI{3.3}{\volt}  & Digital input                              \\
    BPI2      & 10              & In   & \SI{3.3}{\volt}  & Digital input                              \\
    BPI3      & 3               & In   & \SI{3.3}{\volt}  & Digital input                              \\[3pt]
    BPO0      & 4               & Out  & \SI{3.3}{\volt}  & Digital output                             \\
    BPO1      & 12              & Out  & \SI{3.3}{\volt}  & Digital output                             \\
    BPO2      & 13              & Out  & \SI{3.3}{\volt}  & Digital output                             \\
    BPO3      & 6               & Out  & \SI{3.3}{\volt}  & Digital output                             \\[3pt]
    GND       & 0, 2, 5, 11, 14 & —    & \SI{0}{\volt}    & Ground return                              \\
    \bottomrule
  \end{tabular}
  \caption{Backplane Connector Pinout}
  \label{tab:backplane}
\end{table}

Backplane connector digital I/O signals are translated from \SI{3.3}{\volt} to \SI{2.5}{\volt} and then connected to \SI{2.5}{\volt} Zynq SoC-Module bank 34. For voltage translation we selected a Texas Instrument SN74AXC8T245QPWRQ1 automotive \SI{8}{\bit} \SI{380}{\mega bps} dual-supply bus transceiver with ESD protection.

\subsection{USB-C Connector}

USB-C connector is used to program through JTAG and communicate through USART with Zynq SoC-Module using a USB converter.

Selected USB converter is FTDI FT2232HL USB Hi-Speed to Dual Channel Serial UART/FIFO/JTAG/SPI/I2C IC. FT2232HL \texttt{ADBUS} is used for JTAG and \texttt{BDBUS} us used for UART. UART \texttt{RXD} (Zynq to host) is connected to Zynq \texttt{MIO15} and \texttt{TXD} (host to Zynq) is connected to Zynq \texttt{MIO14}. 

\subsection{Gigabit Ethernet Connector}

Gigabit ethernet connector is RJ45 connector used for communication between Zynq SoC-Module Ethernet PHY and host for configuration, telemetry and video streaming.

Selected Gigabit ethernet connector is Taoglas TMJG4820GENL industrial grade RJ45 connector with integrated magnetics 1G Base-T that features EMI finger and short body. Internal LEDs are disabled. 

\subsection{Video Input Connector}

Video input connector contains 4 differential video input pairs and also provides $\pm$\SI{15}{\volt} analog input to power external pre-amplifiers.

Selected video input connector is TE Connectivity 5747841-4 15-position D-Sub plug male pins connector. \autoref{tab:video} shows video input connector pinout.

\begin{table}[ht]
  \centering
  \begin{tabular}{l c l c l}
    \toprule
    Pin name  & Pin no.     & Dir. & Level            & Description                                \\
    \midrule
    +15VA 	& 1   	& Out  	& \SI{15}{\volt}   	& Analog power output          	\\
    -15VA  	& 8 	& Out  	& \SI{-15}{\volt} 	& Analog power output  			\\[3pt]
	
	IN0+	& 10	& In	& $\pm$\SI{15}{\volt}					& Channel 0 Video Input +		\\
	IN0-	& 2	    & In	& $\pm$\SI{15}{\volt}					& Channel 0 Video Input -		\\
	IN1+	& 4	    & In	& $\pm$\SI{15}{\volt}					& Channel 1 Video Input +		\\
	IN1-	& 11	& In	& $\pm$\SI{15}{\volt}					& Channel 1 Video Input -		\\
	IN2+	& 13	& In	& $\pm$\SI{15}{\volt}					& Channel 2 Video Input +		\\
	IN2-	& 5	    & In	& $\pm$\SI{15}{\volt}					& Channel 2 Video Input -		\\
	IN3+	& 7	    & In	& $\pm$\SI{15}{\volt}					& Channel 3 Video Input +		\\
	IN3-	& 14	& In	& $\pm$\SI{15}{\volt}					& Channel 3 Video Input -		\\[3pt]
	
    GND    	& 3, 6, 9, 12, 15 & —    & \SI{0}{\volt}    & Ground return  		\\

    \bottomrule
  \end{tabular}
  \caption{Video Input Connector Pinout}
  \label{tab:video}
\end{table}

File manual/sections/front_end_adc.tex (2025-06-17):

\section{Analog Front-End and ADC}

The analog front-end of the 4-channel ADC module is organized as two-stage chain that conditions each video input before digitalization. \autoref{fig:front_end_adc} illustrates the complete signal path for a single video channel. First, a low-noise instrumentation amplifier provides a well-defined return path, input impedance and gain for the input differential signal from detector. Second, a Fully Differential amplifier implements a low-pass filter and sets common-mode voltage for ADC. And finally, a high-speed SAR ADC samples the video signal and send data to Zynq SoC through \SI{2.5}{\volt} LVDS.

\begin{figure}[ht]
  \centering
  
  \caption{Analog Front-End and ADC Circuit.}
  \label{fig:front_end_adc}
\end{figure}

Using Analog Devices Signal Chain Designer, the total noise refered to the input from \SI{0.1}{\hertz} to \SI{5}{\mega\hertz} is \SI{12.9}{\micro\volt_{rms}}, where:

\begin{itemize}
    \item Instrumentation amplifier: \SI{2.94}{\micro\volt_{rms}}.
    \item Fully differential amplififer: \SI{3.52}{\micro\volt_{rms}}.
    \item ADC: \SI{12}{\micro\volt_{rms}}.
\end{itemize}

Referred to front-end input:
\begin{itemize}
  \item Input signal swing: $v_\text{in}^\text{max} = 8.192/4 = \SI{2.05}{\volt}$ (DC gain of \SI{4}{\volt/\volt} and ADC input range of \SI{8.192}{\volt}).
  \item AC max signal: $v_\text{in,AC}^\text{max} = v_\text{in}^\text{max}/2/\sqrt{2} = \SI{723}{\milli\volt_{rms}}$.
  \item Signal chain noise: $n_\text{in} = \SI{12.9}{\micro\volt_{rms}}$.
  \item The Signal-to-Noise ratio (SNR): $20\log_{10}(v_\text{in,AC}^\text{max}/n_\text{in}) = \SI{94.99}{\decibel}$.
  \item Effective-Number-of-Bits (ENOB) without distortion: $(\text{SNR} - 1.76)/6.02 = \SI{15.49}{\bit}$.
\end{itemize}

\subsection{Instrumentation Amplifier}

\autoref{fig:inst_amp} shows the two opamp instrumentation amplifier equivalent circuit. Resistor $R_1=\SI{1}{\kilo\ohm}$ and $R_2=\SI{10}{\kilo\ohm}$ define input impedance, common mode path and return path for video input. Output common-mode voltage is maintaned and differential gain $G_1$ is set by $R_3 = \SI{665}{\ohm}$ and $R_4 = \SI{1}{\kilo\ohm}$ $\pm$\SI{0.1}{\percent} as:

\begin{equation}
    G_1 \equiv \frac{v_\text{out}}{v_\text{in}} =\frac{{v_\text{out}^+-v_\text{out}^-}}{v_\text{in}^+-v_\text{in}^-}= 1+\frac{2R_4}{R_3} \approx \SI{4}{\volt/\volt}
\end{equation}

\begin{figure}[ht]
  \centering
  \input{sections/front_end_adc/fig_inst_amp.tex}
  \caption{Instrumentation Amplifier Equivalent Circuit.}
  \label{fig:inst_amp}
\end{figure}

For instrumentation amplifier we selected the Analog Devices ADA4898-2 dual operational amplifier that features:
\begin{itemize}
    \item Ultralow voltage noise: \SI{0.9}{\nano\volt/\sqrtunit{\hertz}} and \SI{2.4}{\pico\ampere/\sqrtunit{\hertz}} at \SI{1}{\kilo\hertz}.
    \item Ultralow distortion: \SI{-93}{\decibel c} at \SI{500}{\kilo\hertz}.
    \item High speed: \SI{65}{\mega\hertz} bandwidth at unity gain.
    \item Unity gain stable.
    \item Low input offset: \SI{160}{\micro\volt} maximum.
\end{itemize}

\subsection{Fully Differential Amplifier}

\autoref{fig:fda} shows the fully differential circuit equivalent circuit. Resistors $R_1=R_2=\SI{1}{\kilo\ohm}$ $\pm$ \SI{0.1}{\percent} define input impedance and differential gain. Output common-mode voltage is set externally by ADC to \SI{2.048}{\volt} and differential gain $G_2$ is set as:

\begin{equation}
    G_2 \equiv \frac{v_\text{out}}{v_\text{in}} =\frac{{v_\text{out}^+-v_\text{out}^-}}{v_\text{in}^+-v_\text{in}^-}= \frac{R_2}{R_1} = \SI{1}{\volt/\volt}
\end{equation}

The bandwidth BW is defined by $R_2$ and $C_1=\SI{300}{\pico\farad}$ for \SI{1}{\mega SPS} as:

\begin{equation}
    \text{BW} = \frac{1}{2\pi R_2 C_1} \approx \SI{530}{\kilo\hertz}
\end{equation}

\begin{figure}[ht]
  \centering
  \input{sections/front_end_adc/fig_fda.tex}
  \caption{Fully Differential Amplifier Equivalent Circuit.}
  \label{fig:fda}
\end{figure}

As fully differential amplifier we selected the Analog Devices ADA4945-1 in full-power mode that features:

\begin{itemize}
    \item Rail-to-rail output.
    \item \SI{4}{\milli\ampere} at full-power mode.
    \item \SI{145}{\mega\hertz} bandwidth at gain 1 at full-power mode.
    \item Low noise: \SI{2}{\nano\volt/\sqrtunit{\hertz}} at \SI{100}{\kilo\hertz}.
    \item \SI{115}{\micro\volt} maximum offset voltage.
\end{itemize}

\subsection{Analog-to-Digital Converter (ADC)}

\autoref{fig:filter} shows ADC input filter equivalent circuit. For an \SI{18}{\bit}, the error of a full scale range (FS) step in a single-pole $RC$ filter after acquisition time $t_\text{ACQ}$ is $\exp\left(-\frac{t_\text{ACQ}}{R_\text{filt}C_\text{filt}}\right)\text{FS}$ and a half LSB is approximately $2^{-19}\, \text{FS}$. Then we have

\begin{equation}
    \exp\left(-\frac{t_\text{ACQ}}{R_\text{filt}C_\text{filt}}\right)\text{FS} = 2^{-19}\,\text{FS} \Leftrightarrow C_\text{filt} = \frac{t_\text{ACQ}}{19R_\text{filt}\ln 2}
\end{equation}

\begin{figure}[ht]
  \centering
  \input{sections/front_end_adc/fig_filter.tex}
  \caption{ADC Input filter Equivalent Circuit.}
  \label{fig:filter}
\end{figure}

We selected the Analog Devices LTC2387-18 \SI{18}{\bit} \SI{15}{\mega S P S} SAR ADC that features:

\begin{itemize}
    \item No pipeline delay, no cycle latency.
    \item \SI{95.7}{\decibel} SNR at \SI{1}{\mega\hertz}.
    \item \SI{102}{\decibel} SFDR at \SI{1}{\mega\hertz}.
    \item $\pm$\SI{3}{LSB} INL maximum.
    \item \SI{8.192}{\volt_{p-p}} differential input.
    \item \SI{2.5}{\volt} Serial LVDS interface.
\end{itemize}

For selected ADC we have $t_\text{ACQ} = 1/f_s -\SI{39}{\nano\second}$. For $f_s = \SI{10}{\mega SPS}$ sample rate and $R_\text{filt}=\SI{24.9}{\ohm}$ we get $C_\text{filt}\approx \SI{180}{\pico\farad}$.

To improve ADC reference voltage temperature drift,  reference out pin (\texttt{REFBUF}) is externally driven by Analog Devices LTC6655 \SI{4.096}{\volt} low drift voltage precision reference that features:

\begin{itemize}
  \item Low Noise: \SI{0.25}{ppm_{P-P}} (\SI{0.1}{\hertz} to \SI{10}{\hertz}).
  \item Low drift: \SI{2}{ppm/\degreeCelsius}.
  \item High accuracy: $\pm$\SI{0.025}{\percent} maximum.
  \item Long term drift: \SI{20}{ppm /\sqrtunit{\kilo\hour}}.
\end{itemize}

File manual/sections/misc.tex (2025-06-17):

\section{Miscellaneous}

\subsection{EEPROM}

An EEPROM (Electrically Erasable Programmable Read-Only Memory) is used to store PCB board ID and model.

Selected EEPROM is Microchip 24LC16BT-I/OT \SI{16}{\kilo\bit} non-volatile I2C EEPROM.

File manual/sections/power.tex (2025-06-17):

\section{Power}
\label{sec:power}

\subsection{\SI{12}{\volt} Input Protection}

As \SI{12}{\volt} input protection we use a TPS259480AYWPR Texas Instruments eFuse that features:

To safeguard the \SI{12}{\volt} supply, we employ a Texas Instruments TPS259480A e-Fuse, which integrates back-to-back MOSFETs and offers the following features:

\begin{itemize}
    \item Integrated back-to-back FETs with low ON resistance $R_\mathrm{ON}=\SI{12.2}{\milli\ohm}$.
    \item Ideal diode operation with true reverse current blocking.
    \item Fast overload protection.
    \item Overcurrent protection with load current monitor.
    \item Fast-trip response for short circuit protection.
    \item Adjustable output slew rate.
\end{itemize}

Upstream of the e-Fuse, a TI TVS1800DRV \SI{18}{\volt} flat-clamp transient-voltage suppressor absorbs voltage spikes and surges on the \SI{12}{\volt} line. Downstream, a B520C \SI{20}{\volt}, \SI{5}{\ampere} Schottky diode provides secondary overvoltage protection at the e-Fuse output. \autoref{fig:power_12vin} illustrate the complete \SI{12}{\volt} input protection circuit.

\begin{figure}[ht]
  \centering
  
  \caption{\SI{12}{\volt} Input Protection Circuit}
  \label{fig:power_12vin}
\end{figure}

\subsection{Digital \SI{3.3}{\volt} (3V3D)}

Digital \SI{3.3}{\volt} serves as the primary supply for the Zynq SoC and feeds the \SI{2.5}{\volt} digital LDO used by the ADC. We selected the Analog Devices LT8642S synchronous step-down converter, which provides:
\begin{itemize}
    \item Ultra low EMI emissions (Silent Switcher 2 Architecture).
    \item High efficiency: up to 95\% efficiency at \SI{2}{\mega\hertz}, \SI{12}{\volt} input and \SI{3.3}{\volt} output.
    \item Up to \SI{10}{\ampere} output current.
    \item External compensation.
\end{itemize}

The LT8642S is configured to operate at \SI{2}{\mega\hertz} (see \autoref{fig:power_3v3d}). A Coilcraft XGL1010-801 shielded inductor (\SI{0.8}{\micro\henry}, \SI{0.88}{\milli\ohm} DCR) minimizes losses. Upstream of the converter input, a $\pi$ LC filter suppresses input noise. Power-Good output (\texttt{3V3D\_PG}) and the SYNC pin (\texttt{3V3D\_SYNC}) are both tied back to the Zynq SoC for voltage monitoring and clock synchronization. See LTSpice and LTPoweCAD simulation files for transient and frequency compensation design.

\begin{figure}[ht]
  \centering
  
  \caption{Digital \SI{3.3}{\volt} Step-Down DC-DC Converter Circuit}
  \label{fig:power_3v3d}
\end{figure}

\subsection{Analog \SI{5.5}{\volt} (5V5A)}

Analog \SI{5.5}{\volt} (5V5A) powers low noise analog LDO that supply analog front end and ADC. We selected the Analog Devices LT8624S synchronous step-down DC-DC converter that features:
\begin{itemize}
    \item Ultralow \SI{4}{\nano\volt/\sqrtunit{\hertz}} RMS noise (Silent Switcher 3 architecture).
    \item High efficiency.
    \item Ultra fast transient response: \SI{1}{\micro\second}.
    \item Up to \SI{4}{\ampere} continuous output current.
    \item External compensation.
\end{itemize}

The LT8624S is configured to operate at \SI{2}{\mega\hertz} (see \autoref{fig:power_5v5a}). A Coilcraft XGL1313-222 shielded inductor (\SI{2.2}{\micro\henry}, \SI{1.4}{\milli\ohm} DCR) minimizes losses. Upstream of the converter input, a $\pi$ LC filter suppresses input noise. Enable (\texttt{5V5A\_EN}), Power-Good output (\texttt{5V5A\_PG}) and the SYNC pin (\texttt{5V5A\_SYNC}) are connected to the Zynq SoC for enabling, voltage monitoring and clock synchronization. See LTSpice and LTPoweCAD simulation files for transient and frequency compensation design.

\begin{figure}[ht]
  \centering
  
  \caption{Analog \SI{5.5}{\volt} Step-Down DC-DC Converter Circuit}
  \label{fig:power_5v5a}
\end{figure}

\subsection{Analog \SI{15.5}{\volt} (+15V5A)}

The Analog \SI{15.5}{\volt} (+15V5A) DC-DC converter powers the low-noise Analog \SI{15}{\volt} LDO (15VA). We chose the Analog Devices LT8350S synchronous buck-boost converter that features:

\begin{itemize}
    \item 4-switch single inductor architecture.
    \item Low EMI (Silent Switcher 2 architecture).
    \item Up to 95\% efficiency at \SI{2}{\mega\hertz}.
    \item $\pm$1.5\% output voltage regulation.
    \item External compensation.
\end{itemize}

The LT8350S is configured to operate at \SI{2}{\mega\hertz} (see \autoref{fig:power_15v5a}). A Coilcraft XGL1313-222 shielded inductor (\SI{2.2}{\micro\henry}, \SI{1.4}{\milli\ohm} DCR) minimizes losses. Upstream of the converter input, a $\pi$ LC filter suppresses input noise. Enable (\texttt{15V5A\_EN}), Power-Good output (\texttt{15V5A\_PG}) and the SYNC pin (\texttt{15V5A\_SYNC}) are connected to the Zynq SoC for enabling, voltage monitoring and clock synchronization. See LTSpice and LTPoweCAD simulation files for transient and frequency compensation design.

\begin{figure}[ht]
  \centering
  
  \caption{Analog \SI{15.5}{\volt} Buck-Boost DC-DC Converter Circuit}
  \label{fig:power_15v5a}
\end{figure}

\subsection{Analog \SI{-15.5}{\volt} (-15V5A)}

Analog \SI{-15.5}{\volt} (-15V5A) DC-DC converter powers the low-noise \SI{-15}{\volt} LDO (-15VA). We choose the Analog Devices LT3579 synchronous boost-inverting DC-DC converter that features:
\begin{itemize}
    \item \SI{6}{\ampere}, \SI{42}{\volt} combined power switch.
    \item Output short circuit protection.
    \item Configurable as inverting converter.
    \item External compensation.
\end{itemize}

The LT3579 is configured to operate at \SI{2}{\mega\hertz} (see \autoref{fig:power_n15v5a}). An Eaton DRQ-125-3R3-R coupled inductor (\SI{3.3}{\micro\henry}, \SI{6.3}{\milli\ohm} DCR) minimizes losses. Upstream of the converter input, a $\pi$ LC filter suppresses input noise. Enable (\texttt{-15V5A\_EN}), Power-Good output (\texttt{-15V5A\_PG}) and the SYNC pin (\texttt{-15V5A\_SYNC}) are connected to the Zynq SoC for enabling, voltage monitoring and clock synchronization. See LTSpice for transient design.

\begin{figure}[ht]
  \centering
  
  \caption{Analog \SI{-15.5}{\volt} Inverting DC-DC Converter Circuit}
  \label{fig:power_n15v5a}
\end{figure}

\subsection{Linear Regulators}

The board requires multiple low-noise linear regulators to generate the analog and digital rails from the protected input supply. The following voltages are provided:
\begin{itemize}
    \item Analog Supplies: \SI{15}{\volt} (15VA), \SI{-15}{\volt} (-15VA), \SI{5}{\volt} (5VA), \SI{4.2}{\volt} (4V2A) and \SI{2.5}{\volt} (2V5A) for the analog front-end, ADCs and any external circuitry.
    \item Digital Supplies: \SI{2.5}{\volt} (2V5D) for the ADC LVDS and the Zynq SoC LVDS I/O bank.
\end{itemize}

All rails are generated by Analog Devices LT3042 (15VA), LT3093 (-15VA) and LT3045 (5VA, 4V2A, 2V5A and 2V5D ) ultra-low noise LDOs. These regulators offers:
\begin{itemize}
    \item Extremely low output noise: \SI{0.8}{\micro\volt} RMS (\SI{10}{\hertz} to \SI{100}{\kilo\hertz}) and \SI{2}{\nano\volt/\sqrtunit{\hertz}} at \SI{10}{\kilo\hertz}.
    \item Ultrahigh PSRR: \SI{73}{\decibel} (LT3093), \SI{76}{\decibel} (LT3045) and \SI{79}{\decibel} (LT3042)  at \SI{1}{\mega\hertz}.
    \item \SI{500}{\milli\ampere} (LT3045) and \SI{200}{\milli\ampere} (LT3093 and LT3042) output current.
\end{itemize}

\autoref{fig:power_5va} shows the schematic of the analog \SI{5}{\volt} regulator. Aside from the different resistor values used for setting the output voltage and the power-good feedback network, all LDO circuits follow the same layout. Each device's Enable (\texttt{EN}) and Power-Good (\texttt{PG}) pins are connected back to the Zynq SoC for centralized sequencing and fault monitoring.

\begin{figure}[ht]
  \centering
  
  \caption{Analog \SI{5}{\volt} LDO Circuit}
  \label{fig:power_5va}
\end{figure}

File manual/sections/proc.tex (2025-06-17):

\section{Main Processor}

The main processor is in charge of generating the sequencer signals for reading the detector, configuring integrated circuits, monitoring interlocks, and communicating via Ethernet protocol. As main processor we selected the Trenz Electronic TE0720-04-62I33MA SoC-Module. \autoref{fig:soc} shows TE0720-04-62I33MA SoC-Module.

\begin{figure}[ht]
  \centering
  
  \caption{Trenz Electronic TE0720-04-62I33MA SoC-Module.}
  \label{fig:soc}
\end{figure}

Trenz Electronic TE0720-04-62I33MA SoC-Module features:

\begin{itemize}
    \item AMD Zynq™ XC7Z020-2CLG484I dual ARM® Cortex®-A9 MPCore™ with CoreSight™ System On Chip (SOC) IC Zynq®-7000 Artix™-7 FPGA, 85K Logic Cells 766MHz 484-CSPBGA (19x19).
    \item Rugged for high shock and vibration.
    \item 10/100/1000 tri-speed Gigabit Ethernet transceiver (PHY), SGMII accessible on a board-to-board connector.
    \item 1 GByte (32-bit) DDR3 SDRAM.
    \item 32 MByte QSPI Flash memory (for configuration and operation).
    \item 8 GByte e.MMC.
    \item Plug-on module with 2 x 100-pin and 1 x 60-pin Razor Beam High-Speed hermaphroditic Terminal/Socket Strips.
    \item 152 FPGA I/O's (75 LVDS pairs possible) and 14 MIOs available on board-to-board connectors.
    \item On-board high-efficiency DC-DC converters.
    \item Programmable through Free Vivado Standard Edition Suite.
\end{itemize}

Trenz Electronic TE0720-04-62I33MA SoC-Module is configured as: 

\begin{itemize}
    \item Low jitter clock input for sequencer and DC-DC synchronization from clock generator IC. 
    \item \SI{2.5}{\volt} external power supply for banks 13, 34 and 35. Bank 13 is not powered (unused).
    \item JTAG programming and UART communication through on board FTDI.
    \item \SI{3.3}{\volt} I2C communication through MIO pins for clock generator and EEPROM.
    \item \SI{2.5}{\volt} LVDS differential pair communication with ADC.
    \item Internal \SI{1.8}{\volt} is used for clock generator.
    \item Backplane communication through \SI{2.5}{\volt} to \SI{3.3}{\volt} voltage translator IC.
\end{itemize}

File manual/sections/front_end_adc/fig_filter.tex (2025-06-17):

\begin{tikzpicture}[scale=0.75, transform shape]
    
    \draw (0,0) node[ocirc]{} node[left]{$v_\text{in}^+$} to[R, l=$R_\text{filt}$] ++(2,0) node[circ]{} coordinate(rtop){} -- ++(0.5, 0) node[ocirc]{} node[right]{{$v_\text{out}^+$}};

    \draw (0,-1) node[ocirc]{} node[left]{$v_\text{in}^-$} to[R, l_=$R_\text{filt}$] ++(2,0) node[circ]{} coordinate(rbot){} -- ++(0.5, 0) node[ocirc]{} node[right]{{$v_\text{out}^-$}};

    \draw (rtop) to[C, l_ = $C_\text{filt}$] ++(0,2) node[ground, yscale = -1]{};
    \draw (rbot) to[C, l = $C_\text{filt}$] ++(0,-2) node[ground, yscale = 1]{};

\end{tikzpicture}

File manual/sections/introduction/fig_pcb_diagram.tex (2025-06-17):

\begin{tikzpicture}[
    %=== 1) All the style definitions go here instead of \tikzset in the preamble ===
    block/.style={
    draw,
    rectangle,
    align=center,
    minimum width=3cm,
    minimum height=1.2cm,
    line width=0.4mm
    },
    blockLarge/.style={
    draw,
    rectangle,
    align=center,
    minimum width=3cm,
    minimum height=3cm,
    line width=0.4mm
    },
    blockSmall/.style={
    draw,
    rectangle,
    align=center,
    minimum width=2cm,
    minimum height=0.8cm,
    line width=0.4mm
    },
    node distance=6mm and 10mm
]
%
% Top row
\node[block] (digital_dcdc)    [minimum height=2cm]{Digital\\DC‐DC};
\node[block, anchor=north west] (backplane) at ($(digital_dcdc.north east)+(10mm,0)$) {Backplane\\Connector};
\node[block, anchor=north west] (analog_dcdc)[minimum height=4cm] at ($(backplane.north east)+(10mm,0)$) {Analog\\DC‐DC};
%

\node[block] (clock)     [below=of backplane, minimum width = 3cm] {Clock Gen};

\node[blockSmall] (eeprom)     [below=of clock, minimum width = 3cm, yshift=0.5cm] {EEPROM};
%
% Center block: Zynq SoC
\node[blockLarge] (zynq)       [below=of eeprom, minimum height=4cm, yshift=0.5cm] {Zynq 7020\\SoC-Module};
%
% Left side, middle
\node[block] (gbe)             [below=of digital_dcdc, yshift=0mm] {Gigabit\\Ethernet};
\node[block] (ftdi)            [below=of gbe] {FTDI};

% Bottom‐center row: ADC + Frontend
\node[block] (adc)             [below=of zynq, minimum height=4cm] {4~x~ADC\\+ Frontend};
%
% Bottommost: Input Connector
\node[blockSmall] (input)      [below=of adc, minimum width = 3cm] {Video Input\\Connector};

\node[block] (analog_ldo)      [right=of adc, minimum height=4cm] {Analog\\LDO};
\node[block, anchor=north east] (digital_ldo) at ($(adc.north west)+(-10mm,0)$) {Digital\\LDO};
% \node[block] (digital_ldo)     [left=of adc] {Digital\\LDO};

\node[draw,black,rectangle,fit=(digital_dcdc)(analog_dcdc)(input),inner xsep=6mm, inner ysep=0mm,line width=0.4mm] (border) {};

\end{tikzpicture}

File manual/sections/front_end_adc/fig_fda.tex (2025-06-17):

\begin{tikzpicture}[scale=0.75, transform shape]
    
    \draw (0,0) node[fd op amp] (opamp){};

    \draw (opamp.-) node[circ]{} -- ++(0,1) coordinate(opintop) node[circ]{};
    \draw (opamp.+) node[circ]{} -- ++(0,-1) coordinate(opinbot) node[circ]{};

    \draw (opamp.-) to[R, l_=$R_1$] ++(-2,0) node[ocirc]{} node[left]{$v_\text{in}^-$};
    \draw (opamp.+) to[R, l=$R_1$] ++(-2,0) node[ocirc]{} node[left]{$v_\text{in}^+$};

    \draw (opintop) to[R, l=$R_2$] (opintop -| opamp.out +) node[circ]{} -- (opamp.out +) node[circ]{};
    \draw (opinbot) to[R, l_=$R_2$] (opinbot -| opamp.out -) node[circ]{} -- (opamp.out -) node[circ]{};

    \draw (opintop) node[circ]{} -- ++(0,1.25) coordinate(rtop);
    \draw (opinbot) node[circ]{} -- ++(0,-1.25) coordinate(rbot);
    
    \draw (rtop) to[C, l=$C_1$] (rtop -| opamp.out +) -- (opintop -| opamp.out +);
    \draw (rbot) to[C, l_=$C_1$] (rbot -| opamp.out -) -- (opinbot -| opamp.out -);

    \draw (opamp.out +) -- ++(0.5,0) node[ocirc]{} node[right]{$v_\text{out}^+$};
    \draw (opamp.out -) -- ++(0.5,0) node[ocirc]{} node[right]{$v_\text{out}^-$};

\end{tikzpicture}

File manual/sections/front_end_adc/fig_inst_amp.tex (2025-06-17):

\begin{tikzpicture}[scale=0.75, transform shape]
    
    \draw (0,0) node[circ]{} coordinate(R3bot) to[R, l=$R_3$] ++(0,2) node[circ]{} coordinate (R3top);

    \draw (R3top) -- ++(0,1) node[op amp, yscale=-1, anchor=-] (A1){};
    \draw (R3bot) -- ++(0,-1) node[op amp, yscale=1, anchor=-] (A2){};

    \draw (A1.+) to[short,-*] ++(-2,0) coordinate (R1top);
    \draw (A2.+) to[short,-*] ++(-2,0) coordinate (R1bot);

    \draw (R1top) to[R, l=$R_2$] ++(0, 2) node[ground, yscale = -1]{};
    \draw (R1bot) to[R, l=$R_2$] ++(0, -2) node[ground]{};
    \draw (R1top) to[R, l_=$R_1$] (R1bot);

    \draw (R1top) -- ++(-1,0) node[ocirc]{} node[left]{$v_\text{in}^+$};
    \draw (R1bot) -- ++(-1,0) node[ocirc]{} node[left]{$v_\text{in}^-$};

    \coordinate (aux1) at (R3top -| A1.out);
    \coordinate (aux2) at (R3bot -| A2.out);

    \draw (R3top) to[R, l_=$R_4$] (aux1) -- (A1.out) node[circ]{} -- ++(0.5,0) node[ocirc]{} node[right]{$v_\text{out}^+$};
    \draw (R3bot) to[R, l^=$R_4$] (aux2) -- (A2.out) node[circ]{} -- ++(0.5,0) node[ocirc]{} node[right]{$v_\text{out}^-$};

\end{tikzpicture}

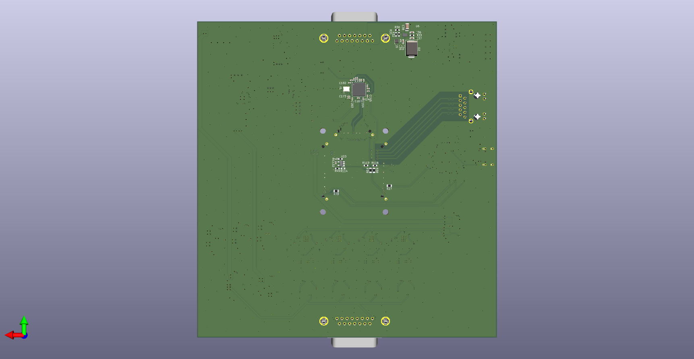
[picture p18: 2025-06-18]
manual/sections/introduction/bottom_view.png

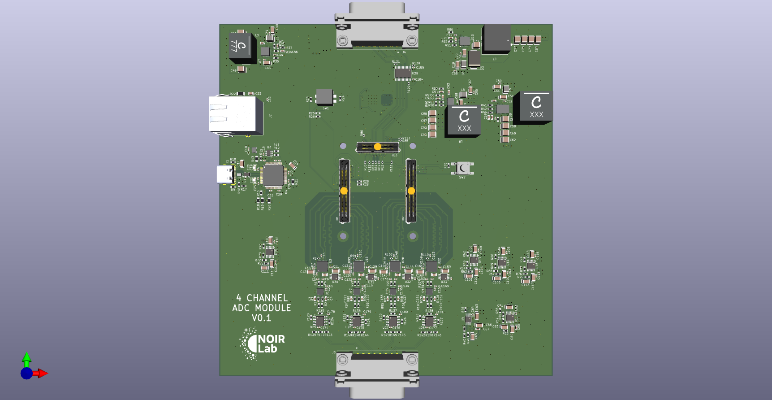
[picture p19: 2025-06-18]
manual/sections/introduction/top_view.png

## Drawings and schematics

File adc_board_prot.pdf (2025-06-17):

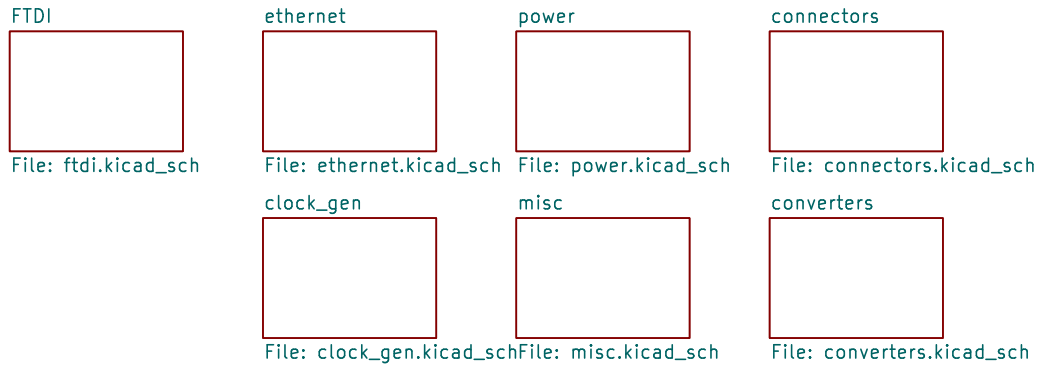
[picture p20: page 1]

converters File: converters.kicad_sch FTDI File: ftdi.kicad_sch

connectors File: connectors.kicad_sch misc File: misc.kicad_sch

Id: 1/26 Title: 4 channel ADC Module

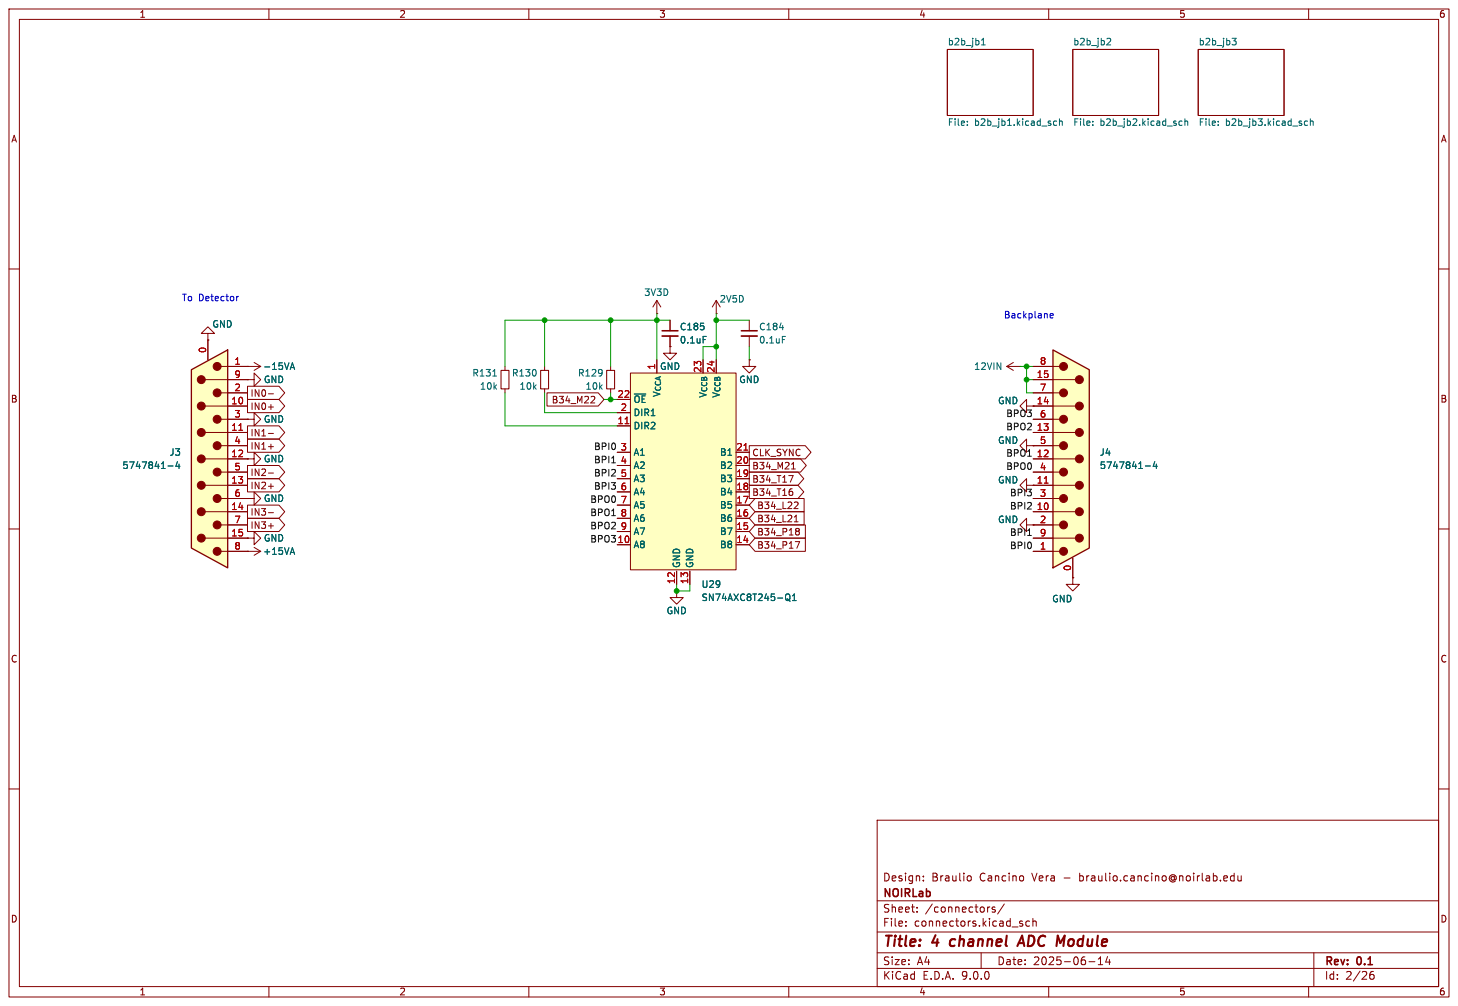
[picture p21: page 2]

0 GND GND GND GND GND

Id: 2/26 Title: 4 channel ADC Module

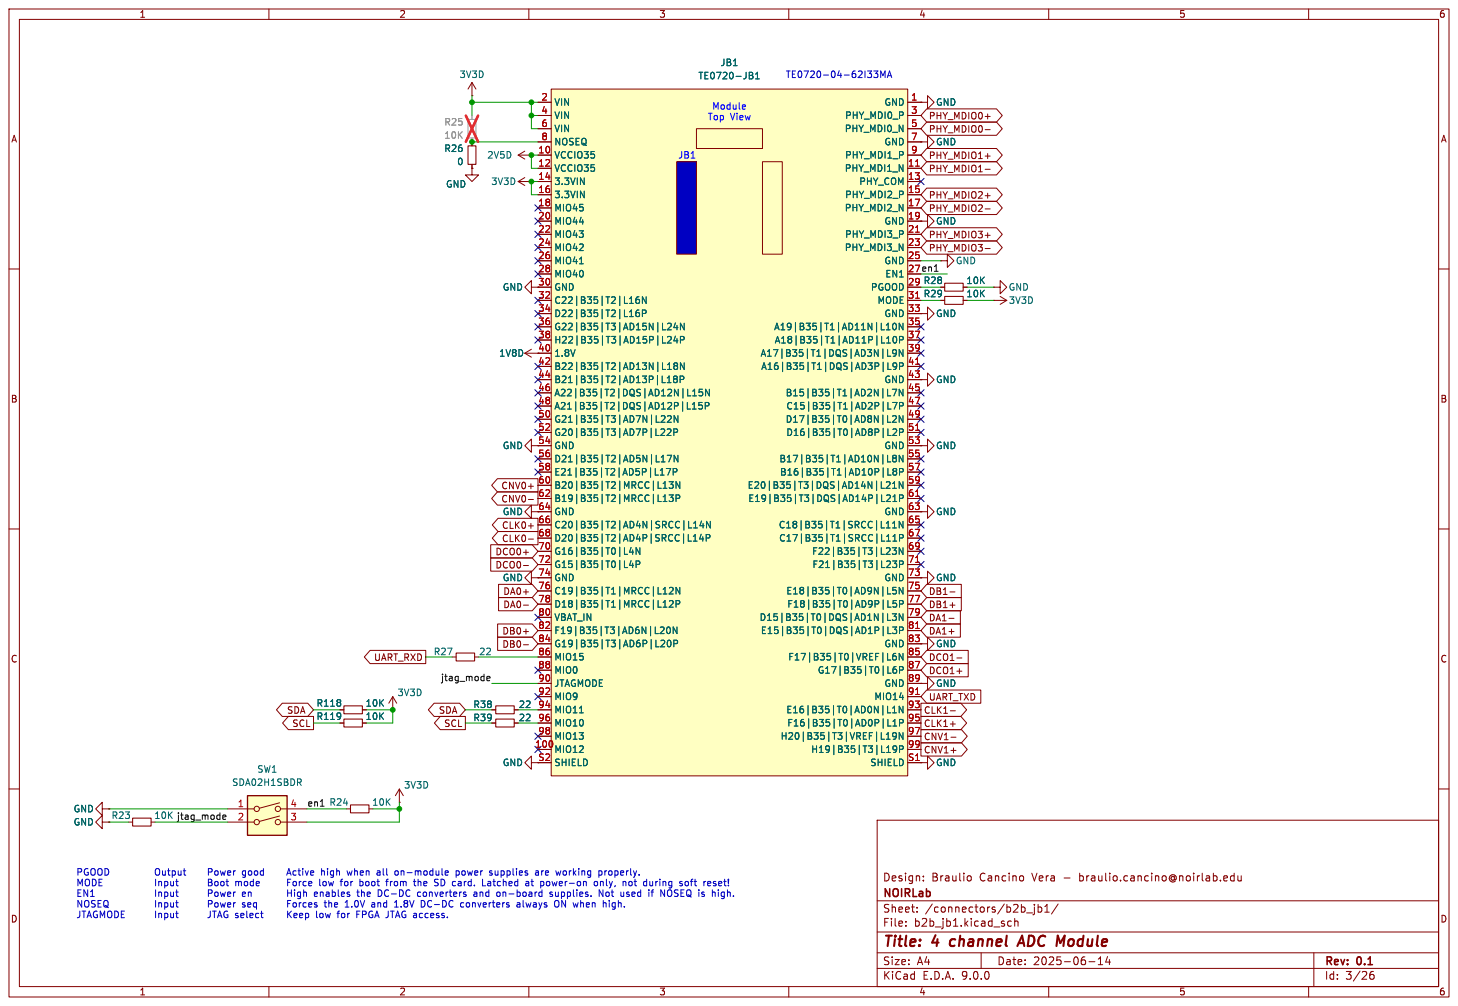
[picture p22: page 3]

Id: 3/26 Title: 4 channel ADC Module

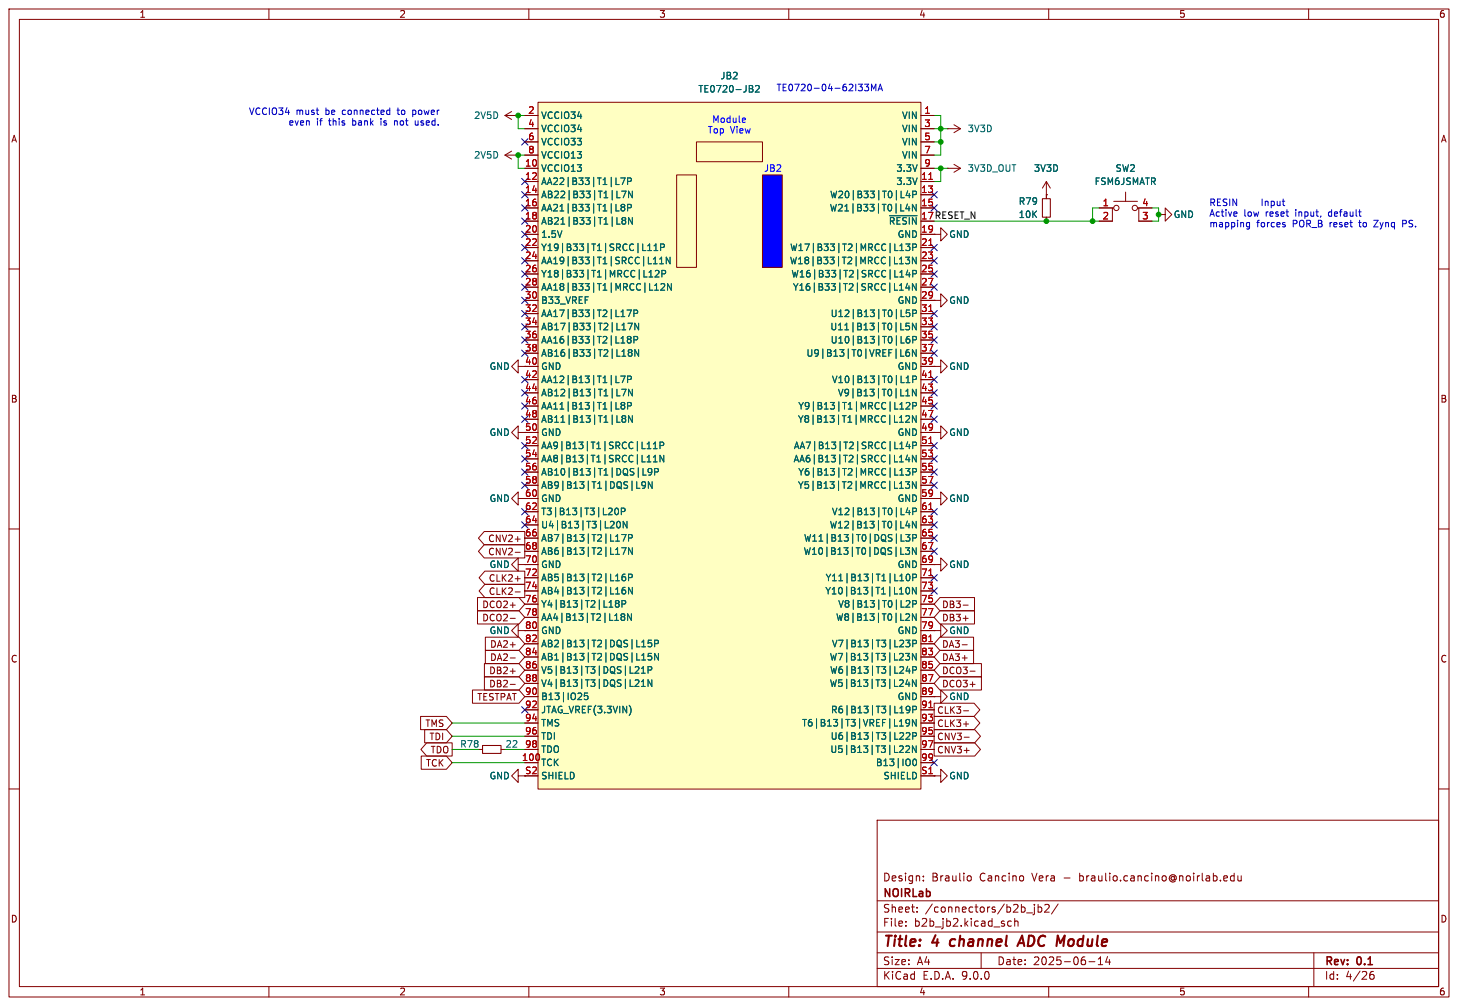
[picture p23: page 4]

Id: 4/26 Title: 4 channel ADC Module

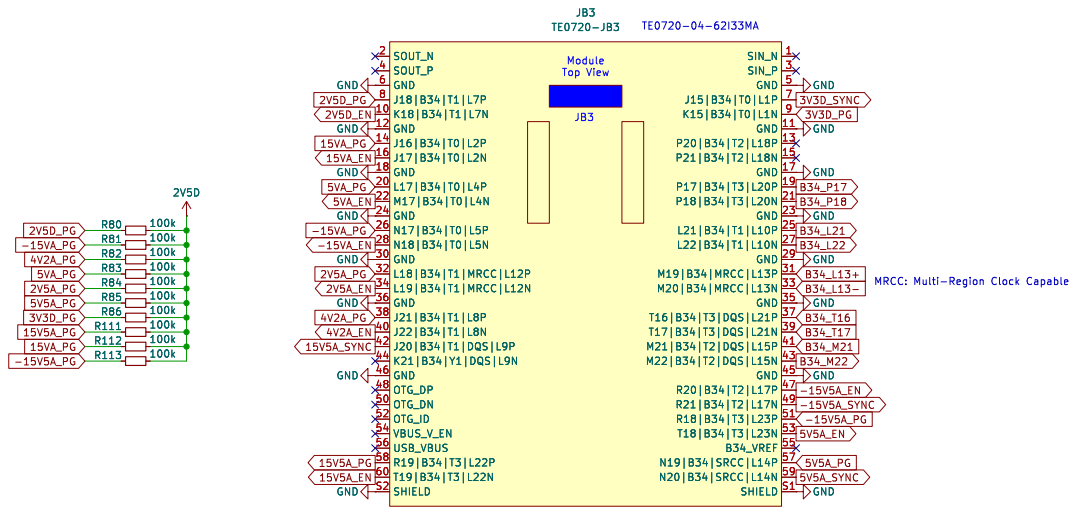
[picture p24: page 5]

GND GND GND

Id: 5/26 Title: 4 channel ADC Module

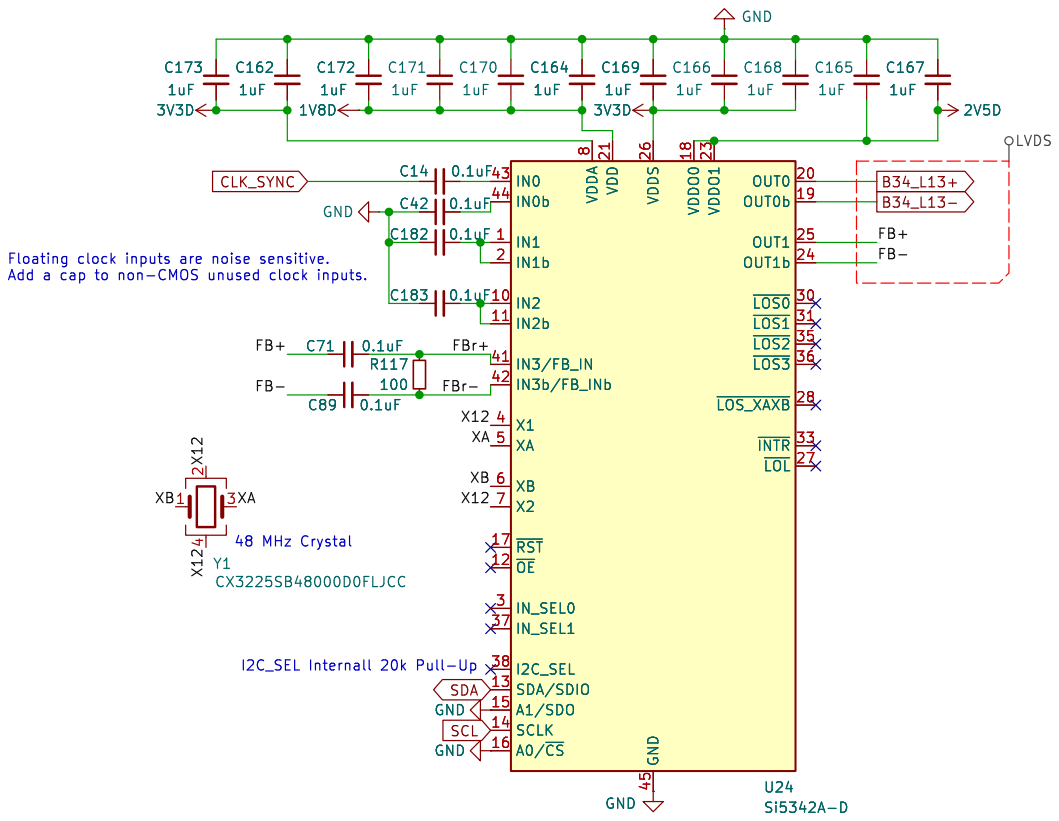
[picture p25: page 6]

8 VDD 21 VDDS 26 GND 45 VDDO0 18 VDDO1 23 OUT0 20 OUT0b 19 OUT1 25 OUT1b 24 ~{LOS0}30 ~{LOS1}31 ~{LOS2}35 ~{LOS3}36 ~{LOS_XAXB} 28 ~{INTR} 33 ~{LOL} 27 U24 Si5342A-D GND

8 VDD 21 VDDS 26 GND 45 VDDO0 18 VDDO1 23 OUT0 20 OUT0b 19 OUT1 25 OUT1b 24 ~{LOS0}30 ~{LOS1}31 ~{LOS2}35 ~{LOS3}36 ~{LOS_XAXB} 28 ~{INTR} 33 ~{LOL} 27 GND

Id: 6/26 Title: 4 channel ADC Module

9 VREGOUT 49 AGND 10 VCORE 12 GND

5 VCORE 64 GND 11 GND 15 GND 25 GND 35 GND 47 VCCIO 20 GND 51 VCCIO 31 VCCIO 42 VCCIO 56 ADBUS0 16 ADBUS1 17 ADBUS2 18 ADBUS3 19 ADBUS4 21 ADBUS5 22 ADBUS6 23 ADBUS7 24 ACBUS0 26 ACBUS1 27 ACBUS2 28 ACBUS3 29 ACBUS4 30 ACBUS5 32 ACBUS6 33 ACBUS7 34 BDBUS0 38 BDBUS1 39 BDBUS2 40 BDBUS3 41 BDBUS4 43 BDBUS5 44 BDBUS6 45 BDBUS7 46 BCBUS0 48 BCBUS1 52 BCBUS2 53 BCBUS3 54 BCBUS4 55 BCBUS5 57 BCBUS6 58 BCBUS7 59 ~{POWEREN} 60 ~{SUSPEND}36 U4 FT2232HL

5 VCORE 64 GND 11 GND 15 GND 25 GND 35 GND 47 VCCIO 20 GND 51 VCCIO 31 VCCIO 42 VCCIO 56 ADBUS0 16 ADBUS1 17 ADBUS2 18 ADBUS3 19 ADBUS4 21 ADBUS5 22 ADBUS6 23 ADBUS7 24 ACBUS0 26 ACBUS1 27 ACBUS2 28 ACBUS3 29 ACBUS4 30 ACBUS5 32 ACBUS6 33 ACBUS7 34 BDBUS0 38 BDBUS1 39 BDBUS2 40 BDBUS3 41 BDBUS4 43 BDBUS5 44 BDBUS6 45 BDBUS7 46 BCBUS0 48 BCBUS1 52 BCBUS2 53 BCBUS3 54 BCBUS4 55 BCBUS5 57 BCBUS6 58 BCBUS7 59 ~{POWEREN} 60 ~{SUSPEND}36 GND

2 OUT 3X1 ECS-2520MVLC-120-CN-TR

Id: 7/26 Title: 4 channel ADC Module

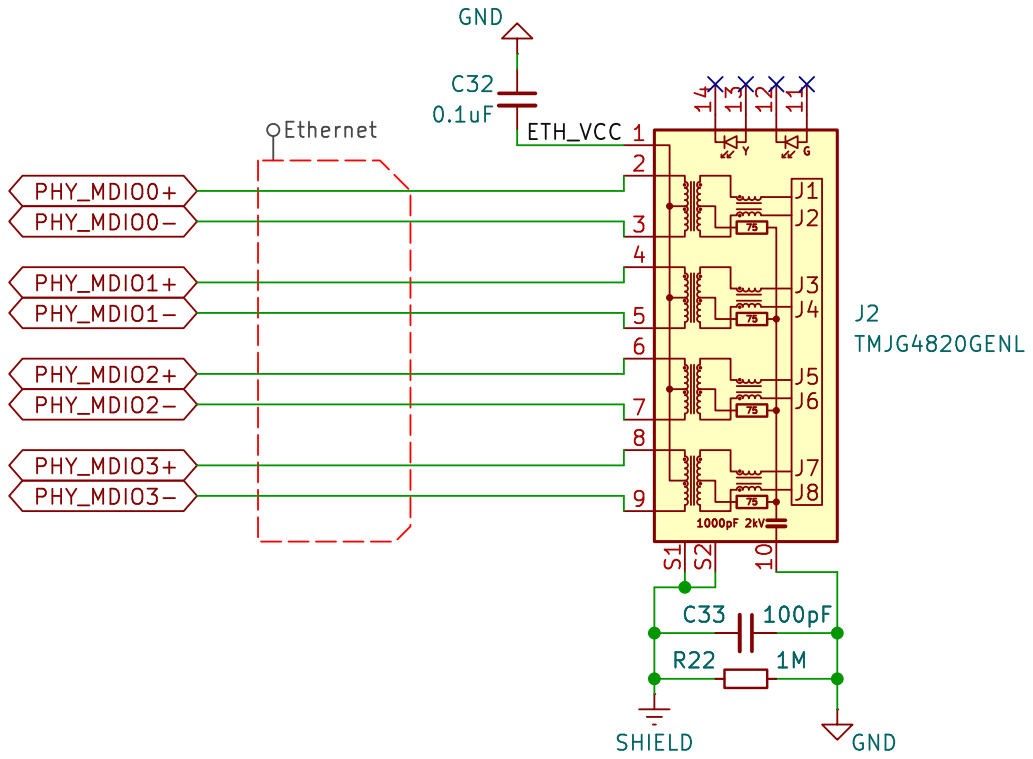
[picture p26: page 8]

Id: 8/26 Title: 4 channel ADC Module

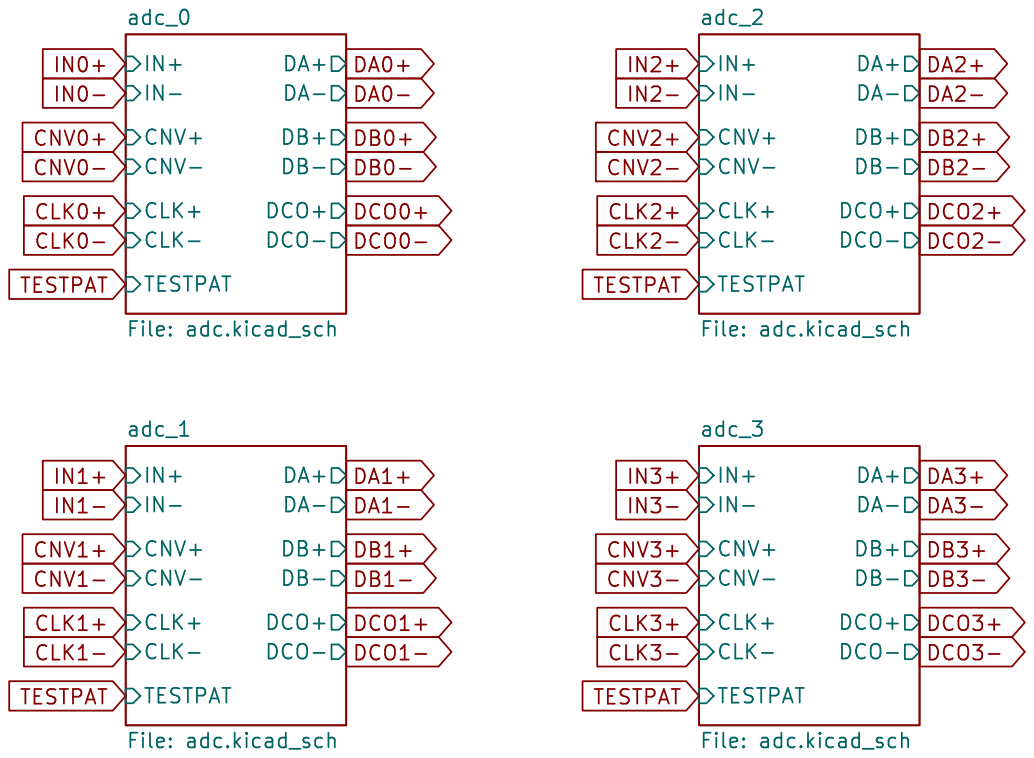
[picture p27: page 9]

Id: 9/26 Title: 4 channel ADC Module

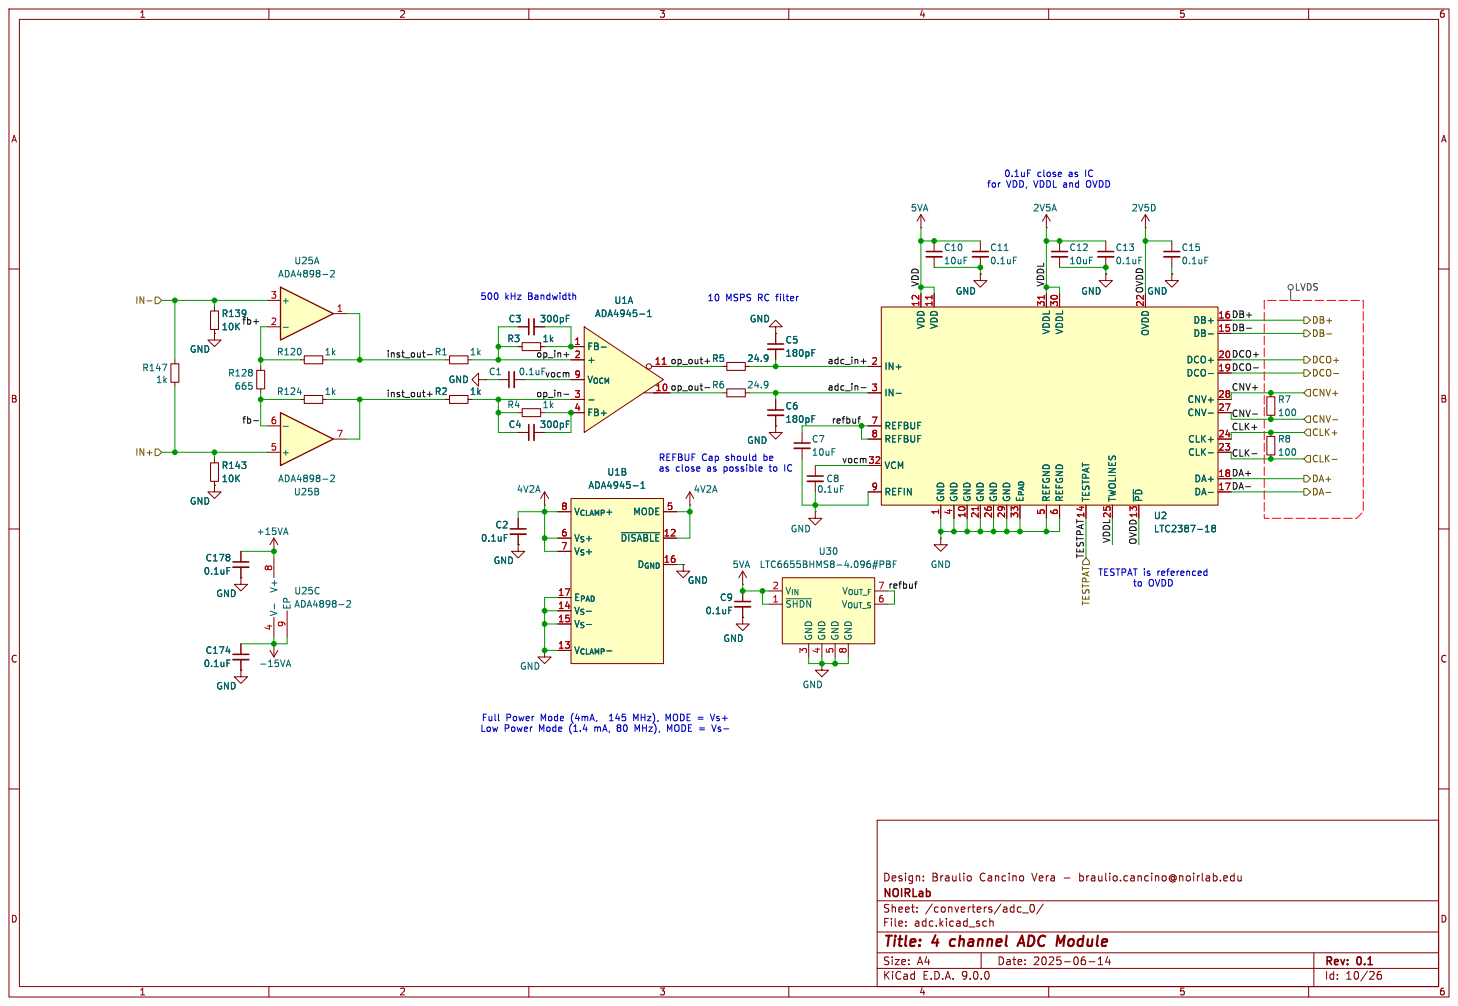
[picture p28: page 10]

0.1uF close as IC
for VDD, VDDL and OVDD

6 TESTPAT 14 TWOLINES 25 ~{PD} 13 OVDD 22 DB+ 16 DB- 15 DCO+ 20 DCO- 19 CNV+ 28 CNV- 27 CLK+ 24 CLK- 23 DA+ 18 DA- 17 GND

4 GND 10 GND 21 GND 26 GND 29 E_{PAD} 33 VDDL 31 REFGND

6 TESTPAT 14 TWOLINES 25 ~{PD} 13 OVDD 22 DB+ 16 DB- 15 DCO+ 20 DCO- 19 CNV+ 28 CNV- 27 CLK+ 24 CLK- 23 DA+ 18 DA- 17 U2

CNV+ DCO- DB- DCO+ DB+ TESTPAT is referenced

Low Power Mode (1.4 mA, 80 MHz), MODE = Vs- REFBUF Cap should be

Id: 10/26 Title: 4 channel ADC Module

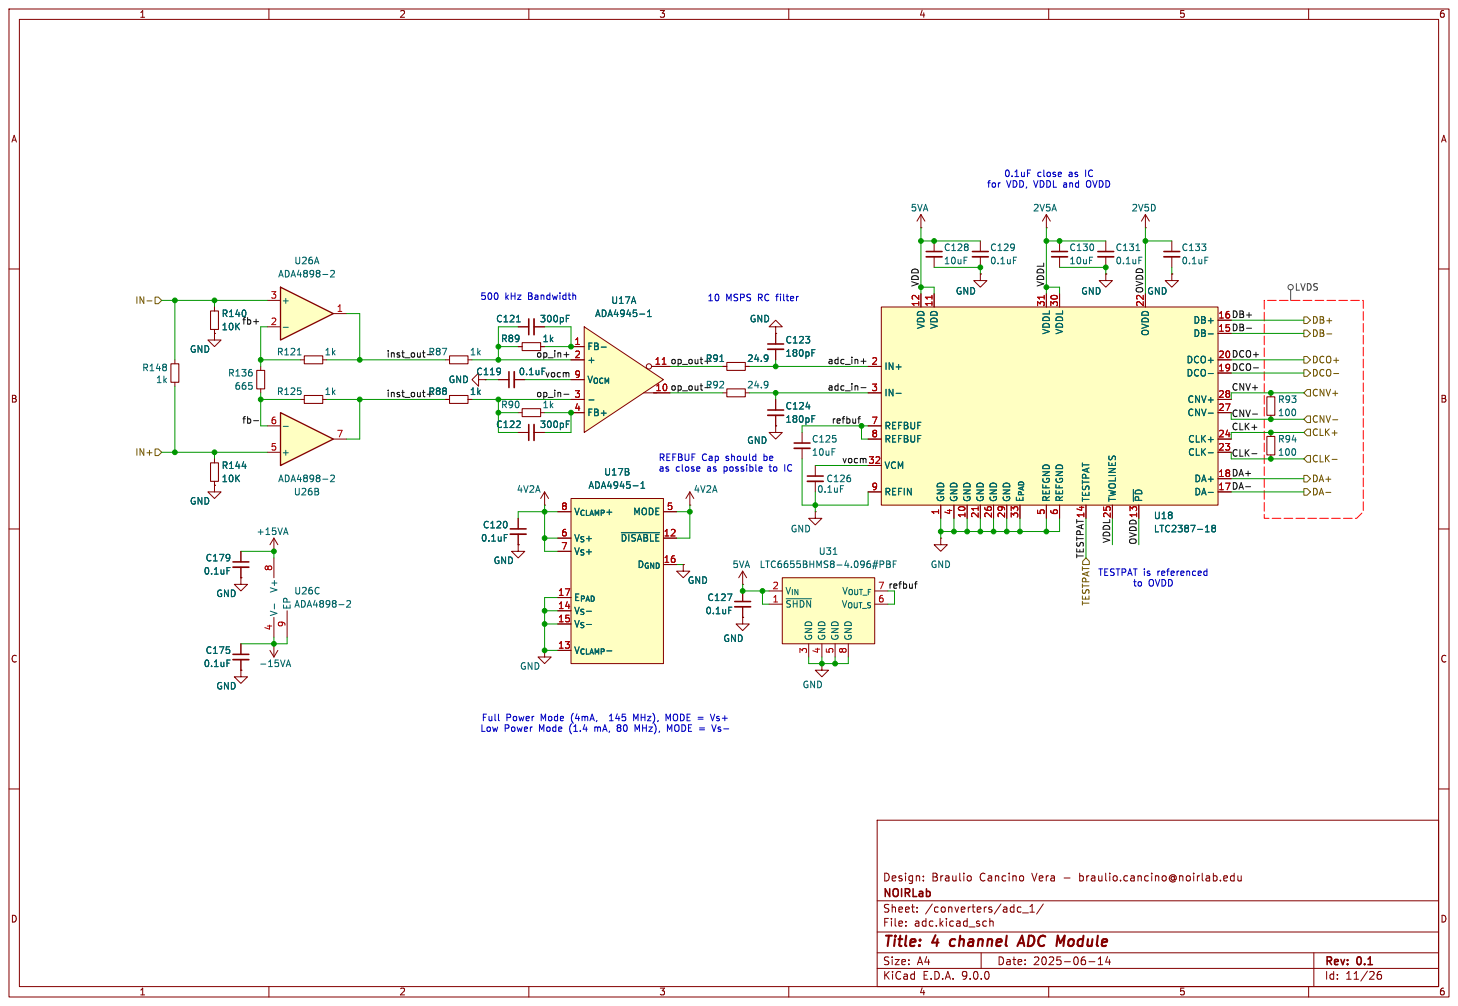
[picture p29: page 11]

DA- DA+ CLK+ CNV- 0.1uF close as IC
for VDD, VDDL and OVDD

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

4 GND 10 GND 21 GND 26 GND 29 E_{PAD} 33 VDDL 31 REFGND

6 TESTPAT 14 TWOLINES 25 ~{PD} 13 OVDD 22 DB+ 16 DB- 15 DCO+ 20 DCO- 19 CNV+ 28 CNV- 27 CLK+ 24 CLK- 23 DA+ 18 DA- 17 U18

Low Power Mode (1.4 mA, 80 MHz), MODE = Vs-

Id: 11/26 Title: 4 channel ADC Module

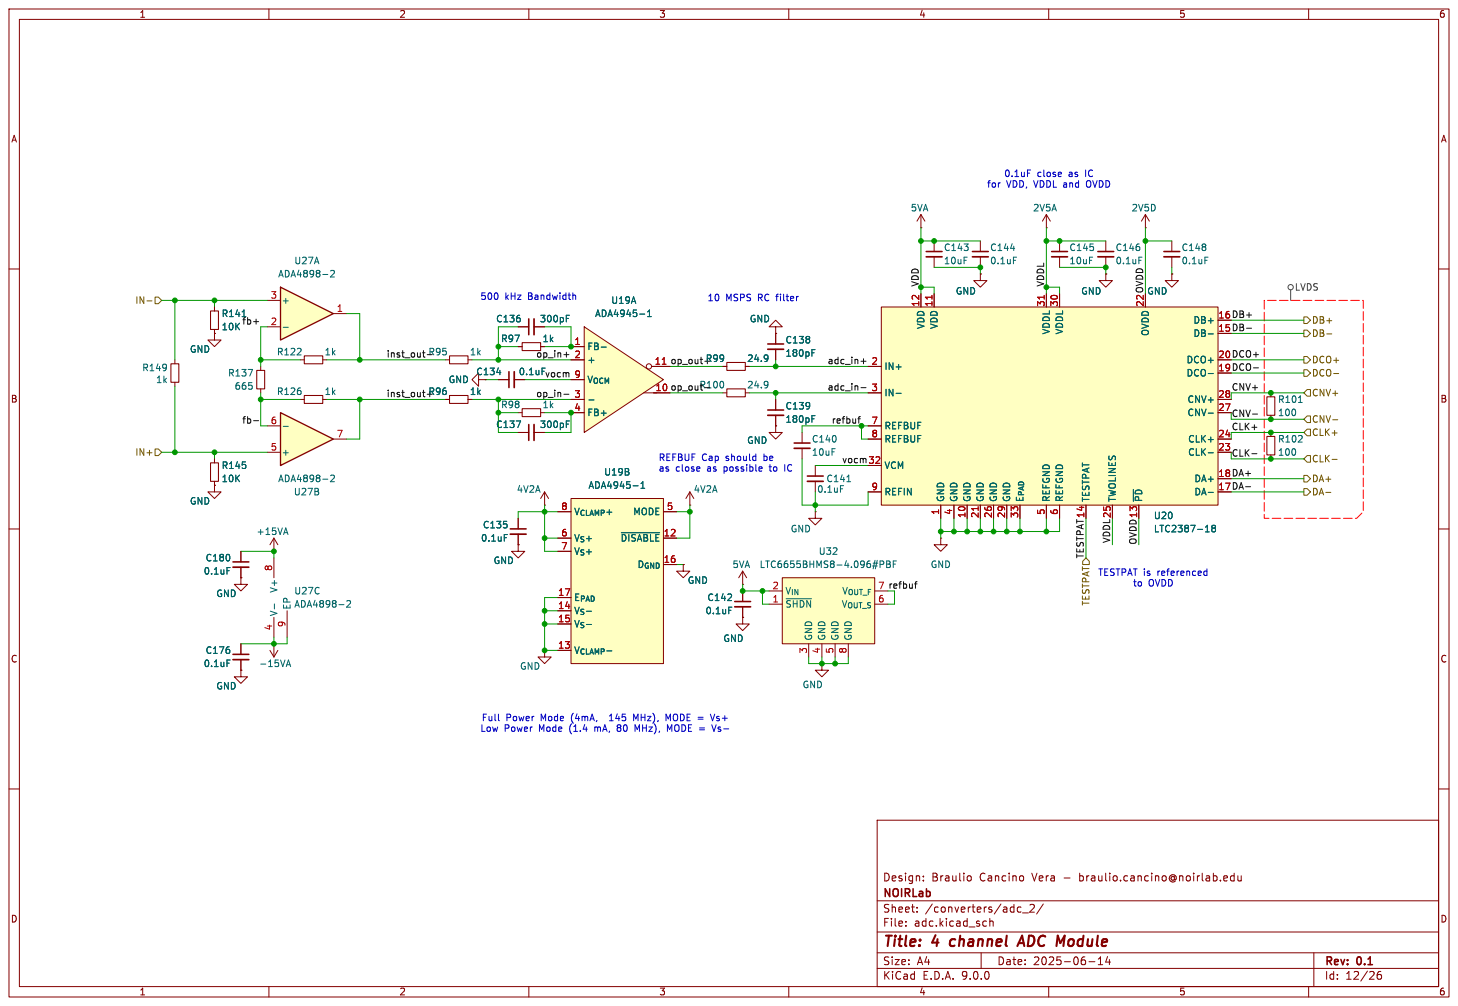
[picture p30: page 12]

DA- DA+ CLK+ CNV- 0.1uF close as IC
for VDD, VDDL and OVDD

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

4 GND 10 GND 21 GND 26 GND 29 E_{PAD} 33 VDDL 31 REFGND

6 TESTPAT 14 TWOLINES 25 ~{PD} 13 OVDD 22 DB+ 16 DB- 15 DCO+ 20 DCO- 19 CNV+ 28 CNV- 27 CLK+ 24 CLK- 23 DA+ 18 DA- 17 U20

Low Power Mode (1.4 mA, 80 MHz), MODE = Vs-

Id: 12/26 Title: 4 channel ADC Module

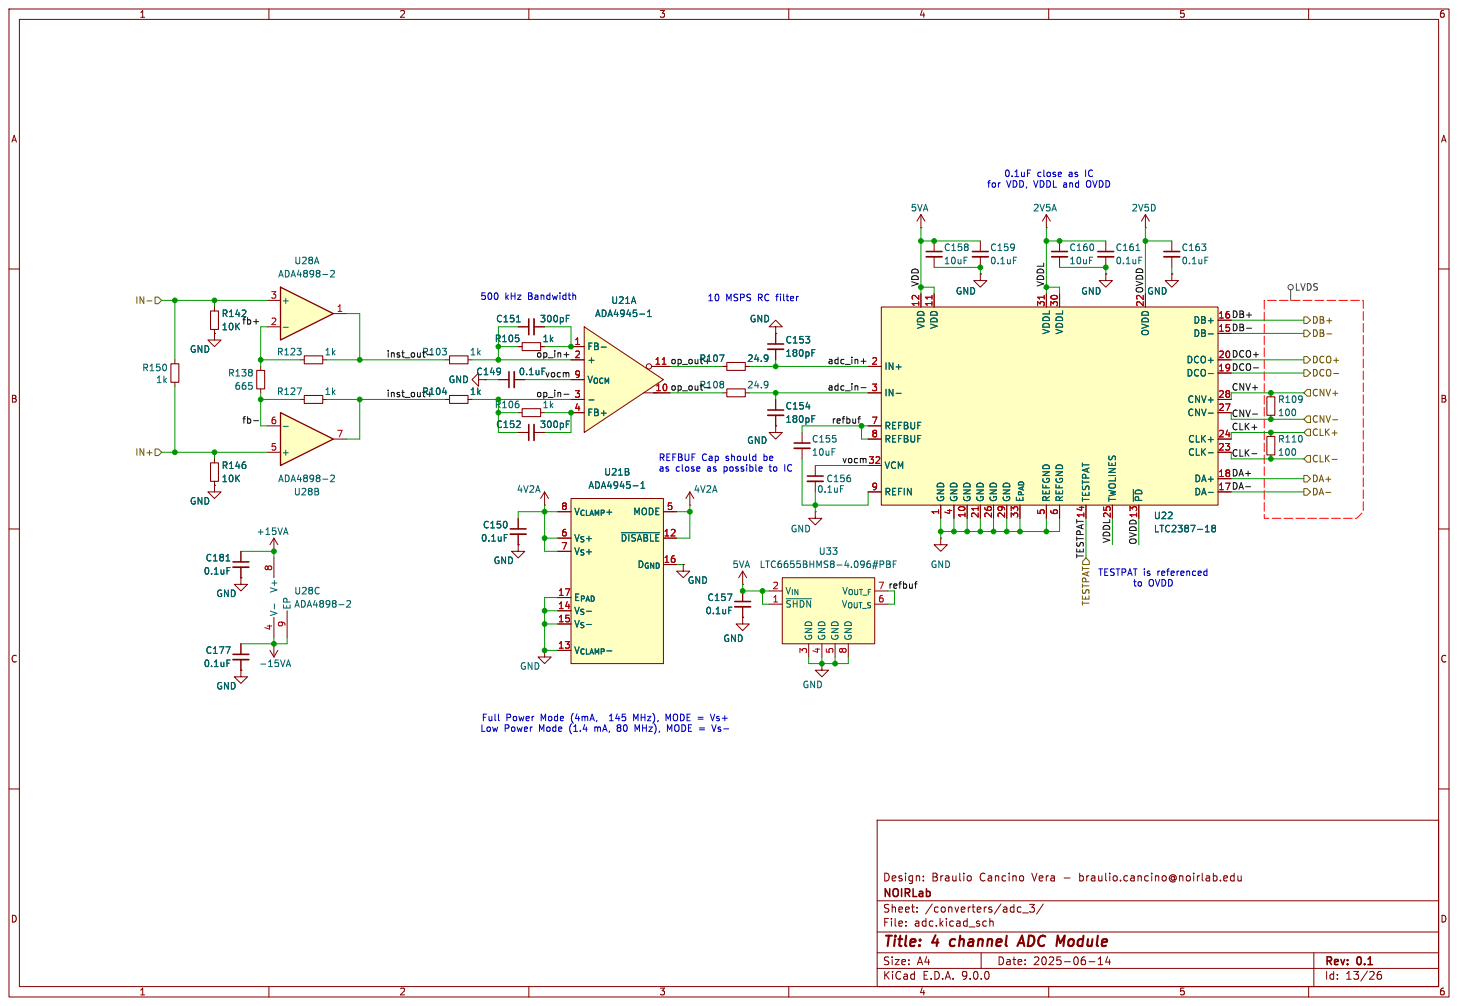
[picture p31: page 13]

0.1uF close as IC
for VDD, VDDL and OVDD

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

4 GND 10 GND 21 GND 26 GND 29 E_{PAD} 33 VDDL 31 REFGND

6 TESTPAT 14 TWOLINES 25 ~{PD} 13 OVDD 22 DB+ 16 DB- 15 DCO+ 20 DCO- 19 CNV+ 28 CNV- 27 CLK+ 24 CLK- 23 DA+ 18 DA- 17 U22

CNV+ DCO- DB- DCO+ DB+ TESTPAT is referenced

Low Power Mode (1.4 mA, 80 MHz), MODE = Vs-

Id: 13/26 Title: 4 channel ADC Module


EEPROM for PCB ID and model U23

Id: 14/26 Title: 4 channel ADC Module


Id: 15/26 Title: 4 channel ADC Module


9 OUT 6 OUT 11 SPLYGD 3 ~{FLT}4 U6 TPS259480AYWPR 12V GND
46.4k 12VIN

Soft Start Charge Time 15.64 ms Current Limit Ilim 4.6 A

Id: 16/26 Title: 4 channel ADC Module


3 GND 16 EPAD 25 EPAD 26 EPAD 27 EPAD 28 C 32 C 31 C 30 C 29 RT 18 BIAS 1 BST 7 SW 12 SW 11 SW 10 SW 9 SW 8 FB 24 PG 23 CLKOUT 19 U7

Id: 17/26 Title: 4 channel ADC Module
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

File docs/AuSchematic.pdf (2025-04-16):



23 | 24
25 | 26





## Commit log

2025-04-18 Change detector connector
    [adc_board_prot.kicad_sch]
2025-04-18 add schematic pdf
2025-04-18 Add BOM
    [BOM.csv]
2025-04-18 edit README.md
    [adc.kicad_sch, b2b_jb1.kicad_sch, b2b_jb2.kicad_sch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]
2025-04-20 Remove floating resistor and reorder schematic pages
    [adc.kicad_sch, adc_board_prot.kicad_pcb, adc_board_prot.kicad_sch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]
2025-04-23 fix via size.
    [adc_board_prot.kicad_pcb]
2025-05-06 Added clock sync and fix minor errors.
    [CX3225SB48000D0FLJCC.step, Si5342A-QFN44_SKY.step, adc.kicad_sch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]
2025-05-21 add instrumentation amplifier front-end
    [adc.kicad_sch, adc_board_prot.kicad_pcb, adc_board_prot.kicad_sch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]
2025-05-21 Fix BOM.csv
    [BOM.csv, adc.kicad_sch, clock_gen.kicad_sch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]
2025-06-03 Split DC DC schematic and improve layout
    [adc.kicad_sch, adc_board_prot.kicad_pcb, b2b_jb3.kicad_sch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]
2025-06-03 Update schematic
2025-06-04 Improve layout
    [adc.kicad_sch, adc_board_prot.kicad_pcb, adc_board_prot.kicad_sch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]
2025-06-17 Major schematic and PCB changes and latex manual creation.
    [BOM.csv, adc.kicad_sch, adc_board_prot.kicad_pcb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]
